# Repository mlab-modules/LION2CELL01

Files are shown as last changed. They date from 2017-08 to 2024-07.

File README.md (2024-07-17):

# LION2CELL01D - Li-ion dual-cell Battery Management Module

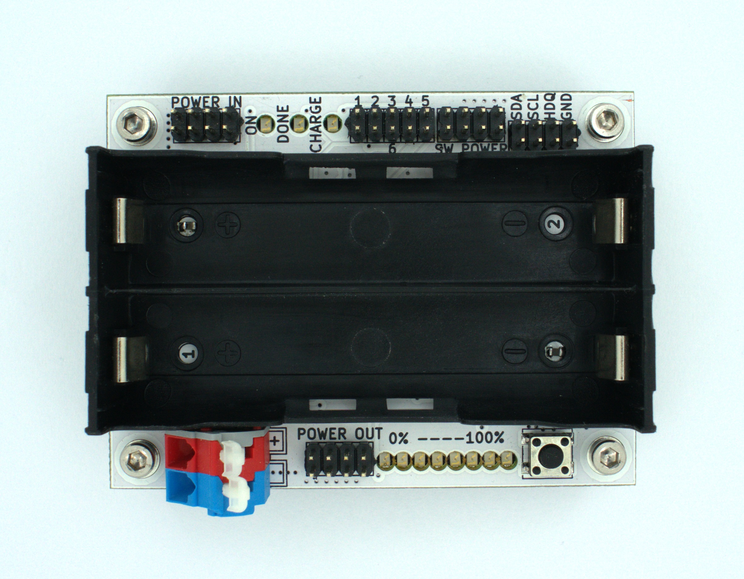
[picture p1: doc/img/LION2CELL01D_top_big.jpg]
LION2CELL01D


## Description

The LION2CELL01D is an integrated battery management solution for 18650 Li-ion batteries. It is designed to manage the charging, balancing, and monitoring of two series-connected Li-ion cells. This module measures the remaining energy, voltage, and temperature of the batteries, and protects against over-voltage and over-draining conditions.

## Features

- **Charging and Balancing**: Supports charging, balancing, and termination with temperature protection.
- **Gas-gauging**: Temperature-compensated gas-gauging for accurate remaining energy estimation.
- **Protection**: Over-voltage, over-current protection, but no under-voltage protection (the module operates until battery depletion).
- **Communication**: Supports I2C and HDQ communication interfaces.

## Technical Specifications

- **Power Supply**: 12 V @ 2 A
- **Charging Current**: Factory set to approximately 1.3 A
- **Battery Holder**: 2x 18650
- **Interfaces**: I2C, HDQ
- **Integrated Circuits**:
  - BQ24103 for charging
  - BQ34Z100 for fuel gauging
- **Dimensions**: 80.77 x 60.45 x 16 mm

## Connection

| Pin | Signal | Description |
|-----|---|---|
| 1 | PG | Power Good |
| 2 | STAT2  | Status Indicator  |
| 3 | GND | Ground |
| 4 | CE | Chip Enable |
| 5 | STAT1  | Status Indicator  |
| 6 | CMODE  | Configuration Mode|

## Construction

The module is constructed with three main functional blocks:
1. **Charging Circuitry**: Manages the charging process of the two series-connected Li-ion cells.
2. **Measurement Circuitry**: Measures the voltage, current, and temperature of the cells.
3. **Balancing and Protection Circuitry**: Ensures cell voltage balancing and provides protection against over-voltage.

### Important Considerations

- Regular charging is required (at least once every six months) to maintain the batteries within operational voltage ranges.
- Specific resistor values and settings are used for the voltage measurement, ensuring accurate readings without exceeding voltage limits.
- The module is equipped with a balancing circuit that discharges one of the cells to match the voltage of the other, with a discharge current around 10 mA.

## Setup and Configuration

1. **Installation**:
   - Check the PCB for proper soldering.
   - Insert the batteries in the designated order: position 1 first, followed by position 2.
   - Verify the operation of the charging function by connecting a 12V adapter.

2. **Software**:
   - Use `setguage2cell.py` to upload parameters to the energy measurement circuit.
   - Parameters are tailored for Panasonic NCR18650B or INR18650MJ1 cells; adjustments are needed for other types.
   - Conduct at least one charge/discharge cycle for accurate energy measurements.

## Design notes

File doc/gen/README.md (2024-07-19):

# PCB

Board size: 80.77x60.45 mm (3.18x2.38 inches)

- This is the size of the rectangle that contains the board
- Thickness: 1.6 mm (63 mils)
- Material: FR4
- Finish: HAL
- Layers: 2
- Copper thickness: 35 µm

Solder mask: TOP / BOTTOM

- Color: Green

Silk screen: TOP / BOTTOM

- Color: White

# Important sizes

Clearance: 0.2 mm (8 mils)

Track width: 0.18 mm (7 mils)

- By design rules: 0.2 mm (8 mils)

Drill: 0.6 mm (24 mils)

- Vias: 0.6 mm (24 mils) [Design: 0.4 mm (16 mils)]
- Pads: 0.7 mm (28 mils)
- The above values are real drill sizes, they add 0.1 mm (4 mils) to plated holes (PTH)

Via: 0.89/0.5 mm (35/20 mils)

- By design rules: 0.4/0.3 mm (16/12 mils)
- Micro via: yes [0.2/0.1 mm (8/4 mils)]
- Buried/blind via: yes
- Total: 267 (thru: 267 buried/blind: 0 micro: 0)

Outer Annular Ring: 0.15 mm (6 mils)

- By design rules: 0.26 mm (10 mils)

Eurocircuits class: 6A
- Using min drill 0.6 mm for an OAR of 0.15 mm

# General stats

Components count: (SMD/THT)

- Top: 2/20 (SMD + THT)
- Bottom: 70/8 (SMD + THT)

Defined tracks:

Used tracks:

- 0.18 mm (7 mils) (279) defined: no
- 0.2 mm (8 mils) (7) defined: no
- 0.25 mm (10 mils) (15) defined: no
- 0.25 mm (10 mils) (5) defined: no
- 0.3 mm (12 mils) (104) defined: no
- 0.4 mm (16 mils) (379) defined: no
- 0.5 mm (20 mils) (88) defined: no
- 0.6 mm (24 mils) (88) defined: no
- 0.89 mm (35 mils) (40) defined: no

Defined vias:

Used vias:

- 0.89/0.5 mm (35/20 mils) (Count: 267, Aspect: 1.8 A) defined: no

Holes (excluding vias):

- 0.6 mm (24 mils) (5)
- 0.89 mm (35 mils) (42)
- 1.0 mm (39 mils) (4)
- 1.3 mm (51 mils) (4)
- 1.6 mm (63 mils) (4)
- 2.7 mm (106 mils) (11)
- 3.0 mm (118 mils) (4)

Oval holes:

Drill tools (including vias and computing adjusts and rounding):

- 0.6 mm (24 mils) (267)
- 0.7 mm (28 mils) (5)
- 1.0 mm (39 mils) (42)
- 1.1 mm (43 mils) (4)
- 1.4 mm (55 mils) (4)
- 1.7 mm (67 mils) (4)
- 2.7 mm (106 mils) (11)
- 3.1 mm (122 mils) (4)

Solder paste stats:

Using a paste with 87.75 % alloy, that has an specific gravity for the alloy of 7.4 g/cm³
and 1.0 g/cm³ for the flux. This paste has an specific gravity of  4.15 g/cm³.

The stencil thickness is  0.12 mm.

| Side | Pads with paste | Area [mm²] | Paste [g] |
|---|---|---|---|
| Top | 4 | 4.97 | 0.02 |
| Bottom | 220 | 364.62 | 1.81 |
| Total  | 224 | 369.58 | 1.84 |

Note: this is just an approximation to the theoretical value. Margins of the solder mask and waste aren't computed.

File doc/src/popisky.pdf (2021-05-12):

List1

Stránka 1

1 – PG | 4 – CE | 1 – PG | 4 – CE | 1 – PG | 4 – CE
2 – STAT2 | 5 – STAT1 | 2 – STAT2 | 5 – STAT1 | 2 – STAT2 | 5 – STAT1
3 – GND | 6 – CMODE | 3 – GND | 6 – CMODE | 3 – GND | 6 – CMODE
1 – PG | 4 – CE | 1 – PG | 4 – CE | 1 – PG | 4 – CE
2 – STAT2 | 5 – STAT1 | 2 – STAT2 | 5 – STAT1 | 2 – STAT2 | 5 – STAT1
3 – GND | 6 – CMODE | 3 – GND | 6 – CMODE | 3 – GND | 6 – CMODE
1 – PG | 4 – CE | 1 – PG | 4 – CE | 1 – PG | 4 – CE
2 – STAT2 | 5 – STAT1 | 2 – STAT2 | 5 – STAT1 | 2 – STAT2 | 5 – STAT1
3 – GND | 6 – CMODE | 3 – GND | 6 – CMODE | 3 – GND | 6 – CMODE
1 – PG | 4 – CE | 1 – PG | 4 – CE | 1 – PG | 4 – CE
2 – STAT2 | 5 – STAT1 | 2 – STAT2 | 5 – STAT1 | 2 – STAT2 | 5 – STAT1
3 – GND | 6 – CMODE | 3 – GND | 6 – CMODE | 3 – GND | 6 – CMODE
1 – PG | 4 – CE | 1 – PG | 4 – CE | 1 – PG | 4 – CE
2 – STAT2 | 5 – STAT1 | 2 – STAT2 | 5 – STAT1 | 2 – STAT2 | 5 – STAT1
3 – GND | 6 – CMODE | 3 – GND | 6 – CMODE | 3 – GND | 6 – CMODE
1 – PG | 4 – CE | 1 – PG | 4 – CE | 1 – PG | 4 – CE
2 – STAT2 | 5 – STAT1 | 2 – STAT2 | 5 – STAT1 | 2 – STAT2 | 5 – STAT1
3 – GND | 6 – CMODE | 3 – GND | 6 – CMODE | 3 – GND | 6 – CMODE
1 – PG | 4 – CE | 1 – PG | 4 – CE | 1 – PG | 4 – CE
2 – STAT2 | 5 – STAT1 | 2 – STAT2 | 5 – STAT1 | 2 – STAT2 | 5 – STAT1
3 – GND | 6 – CMODE | 3 – GND | 6 – CMODE | 3 – GND | 6 – CMODE
1 – PG | 4 – CE | 1 – PG | 4 – CE | 1 – PG | 4 – CE
2 – STAT2 | 5 – STAT1 | 2 – STAT2 | 5 – STAT1 | 2 – STAT2 | 5 – STAT1
3 – GND | 6 – CMODE | 3 – GND | 6 – CMODE | 3 – GND | 6 – CMODE
1 – PG | 4 – CE | 1 – PG | 4 – CE | 1 – PG | 4 – CE
2 – STAT2 | 5 – STAT1 | 2 – STAT2 | 5 – STAT1 | 2 – STAT2 | 5 – STAT1
3 – GND | 6 – CMODE | 3 – GND | 6 – CMODE | 3 – GND | 6 – CMODE
1 – PG | 4 – CE | 1 – PG | 4 – CE | 1 – PG | 4 – CE
2 – STAT2 | 5 – STAT1 | 2 – STAT2 | 5 – STAT1 | 2 – STAT2 | 5 – STAT1
3 – GND | 6 – CMODE | 3 – GND | 6 – CMODE | 3 – GND | 6 – CMODE
1 – PG | 4 – CE | 1 – PG | 4 – CE | 1 – PG | 4 – CE
2 – STAT2 | 5 – STAT1 | 2 – STAT2 | 5 – STAT1 | 2 – STAT2 | 5 – STAT1
3 – GND | 6 – CMODE | 3 – GND | 6 – CMODE | 3 – GND | 6 – CMODE
1 – PG | 4 – CE | 1 – PG | 4 – CE | 1 – PG | 4 – CE
2 – STAT2 | 5 – STAT1 | 2 – STAT2 | 5 – STAT1 | 2 – STAT2 | 5 – STAT1
3 – GND | 6 – CMODE | 3 – GND | 6 – CMODE | 3 – GND | 6 – CMODE
1 – PG | 4 – CE | 1 – PG | 4 – CE | 1 – PG | 4 – CE
2 – STAT2 | 5 – STAT1 | 2 – STAT2 | 5 – STAT1 | 2 – STAT2 | 5 – STAT1
3 – GND | 6 – CMODE | 3 – GND | 6 – CMODE | 3 – GND | 6 – CMODE

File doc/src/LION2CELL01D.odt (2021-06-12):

Modul obsluhující dva sériově zapojené li-on články 18650

Jan Chroust

## Modul je osazen obvodem pro zajištění nabíjení dvou sériově zapojených li-on článků. Samozřejmostí je moderní obvod pro měření zbývající energie a celkové monitorování článků. Výstupem je I2C sběrnice. Článek je ošetřen proti případnému poškození přepětím.

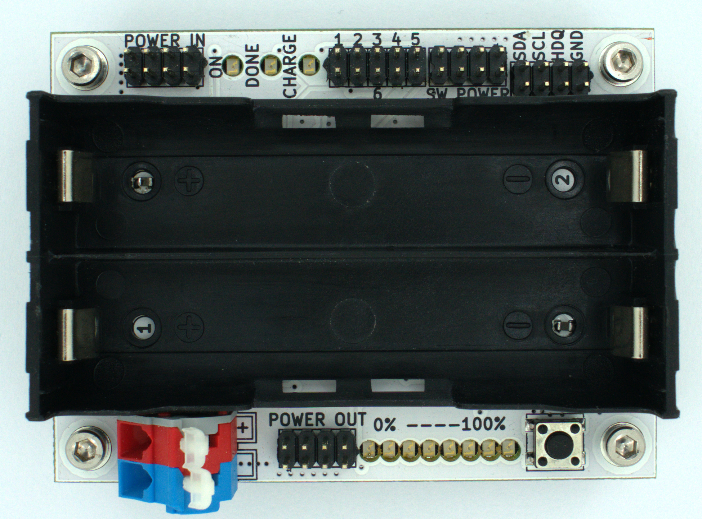
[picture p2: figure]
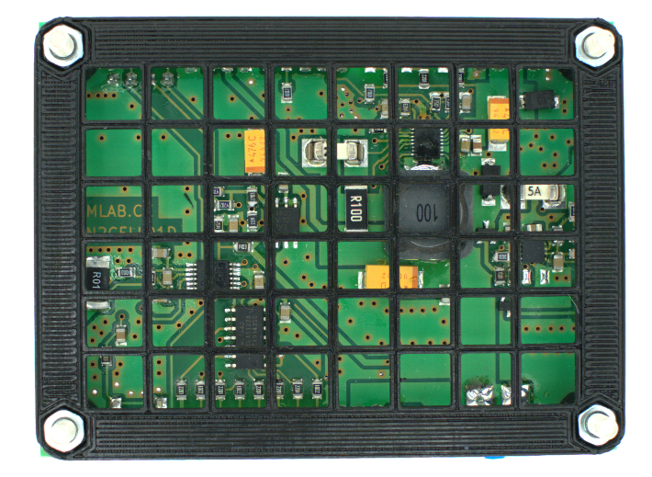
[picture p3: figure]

# Technické parametry

Parametr | Hodnota | Poznámka
Napájení | 12 V@2A | Nabíjecí proud je z výroby nastaven na cca 1,3A
Pouzdro na články | 2x18650
Rozhraní | I2C, HDQ
Integrované obvod: | BQ24103 | Nabíjení
| BQ34Z100 | Měření článku
Rozměry | 80.77 x 60.45 x 16 mm | Výška nad základní deskou

# Popis konstrukce

Modul obsahuje tři samostatné funkční celky – Dobíjecí elektroniku, měření parametrů a balanční a ochranný obvod. Většina z nich pracuje stále i když modul není využíván. Důsledkem je, že modul je nutné pravidelně nabíjet (alespoň jednou za půl roku), aby byly akumulátory udržovány v provozním rozsahu napětí.

## Nastavení děliče u BQ34Z100 pro měření napětí

Dělič pro měření napětí je tvořen odpory R23 a R24. Hodnota napětí na pinu BAT nesmí přesáhnout 900 mV, proto se hodnota odporu vypočítá následujícím vzorcem:

{R} rsub {24} =16500 Ω ( {V} rsub {in max} -900mV)/900mV

Výsledkem je pro dva články 137,5 kΩ, ale z důvodu lepší dostupnosti byl zvolen obvod R24 140kΩ. R23 16k5.

Výpočet hodnoty dělícího poměru v mV, který se zapisuje do nastavení obvodu se dopočítá tímto vzorcem:

Poměr= {1000} over {{R} rsub {23}} *( {R} rsub {23} + {R} rsub {24} )

Po vložení hodnot:

Poměr= {1000} over {16,5} *(16,5+140)

Výsledná hodnota poměru:

Poměr=9484 mV

Po převod na HEX (tato hodnota se vkládá):

Poměr=250C

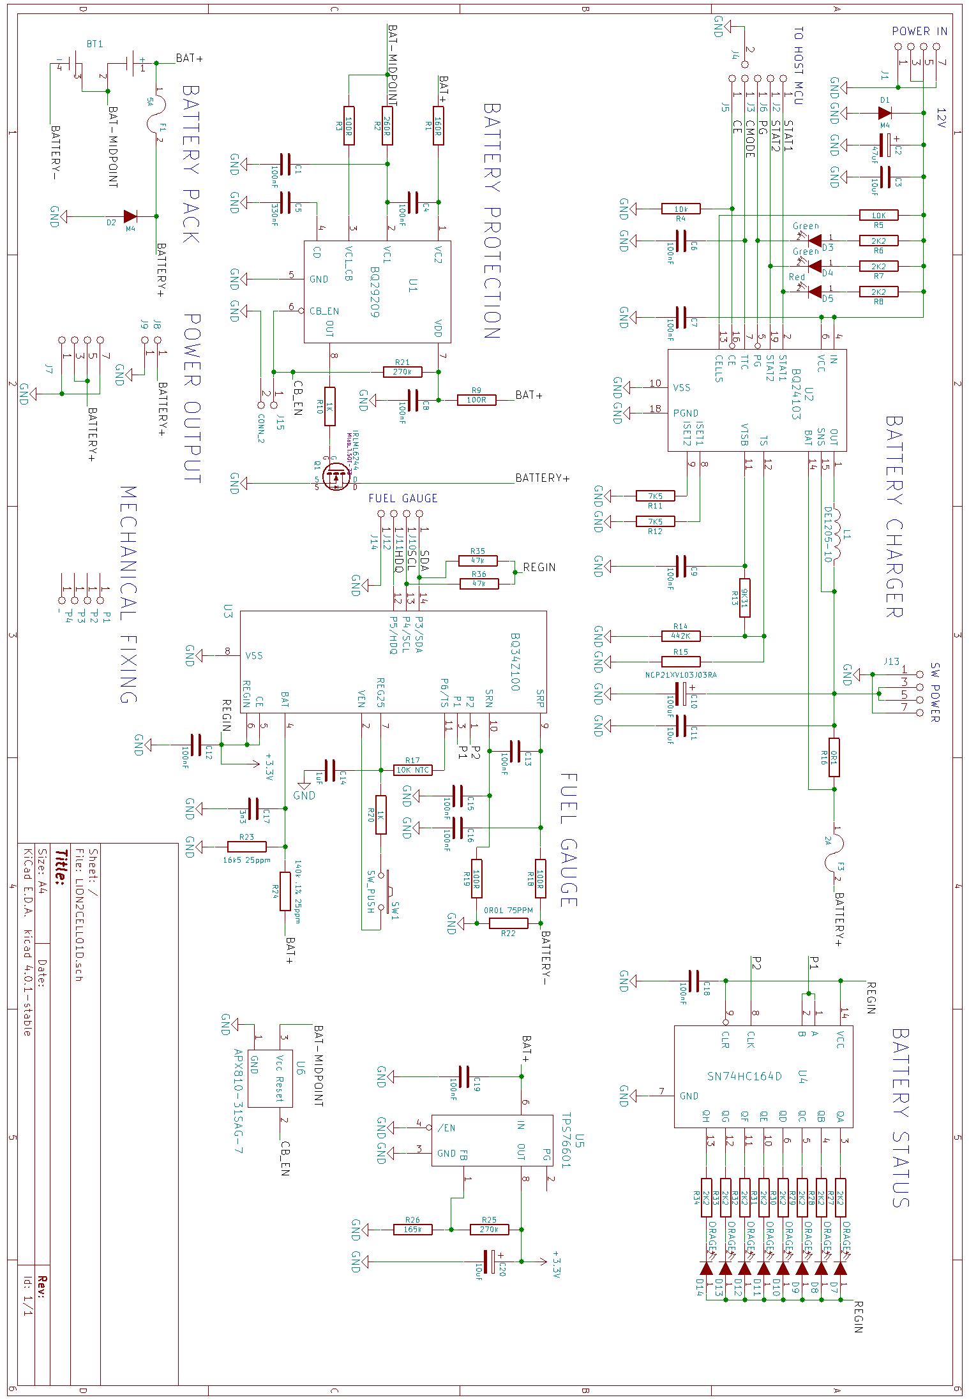
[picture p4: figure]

# Schéma

# Osazení a oživení

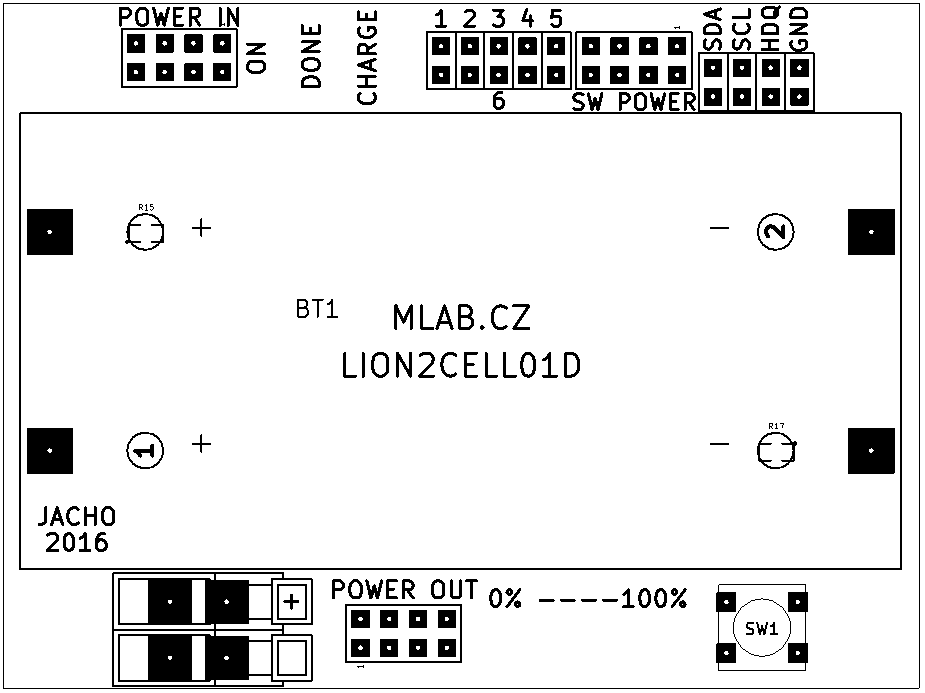
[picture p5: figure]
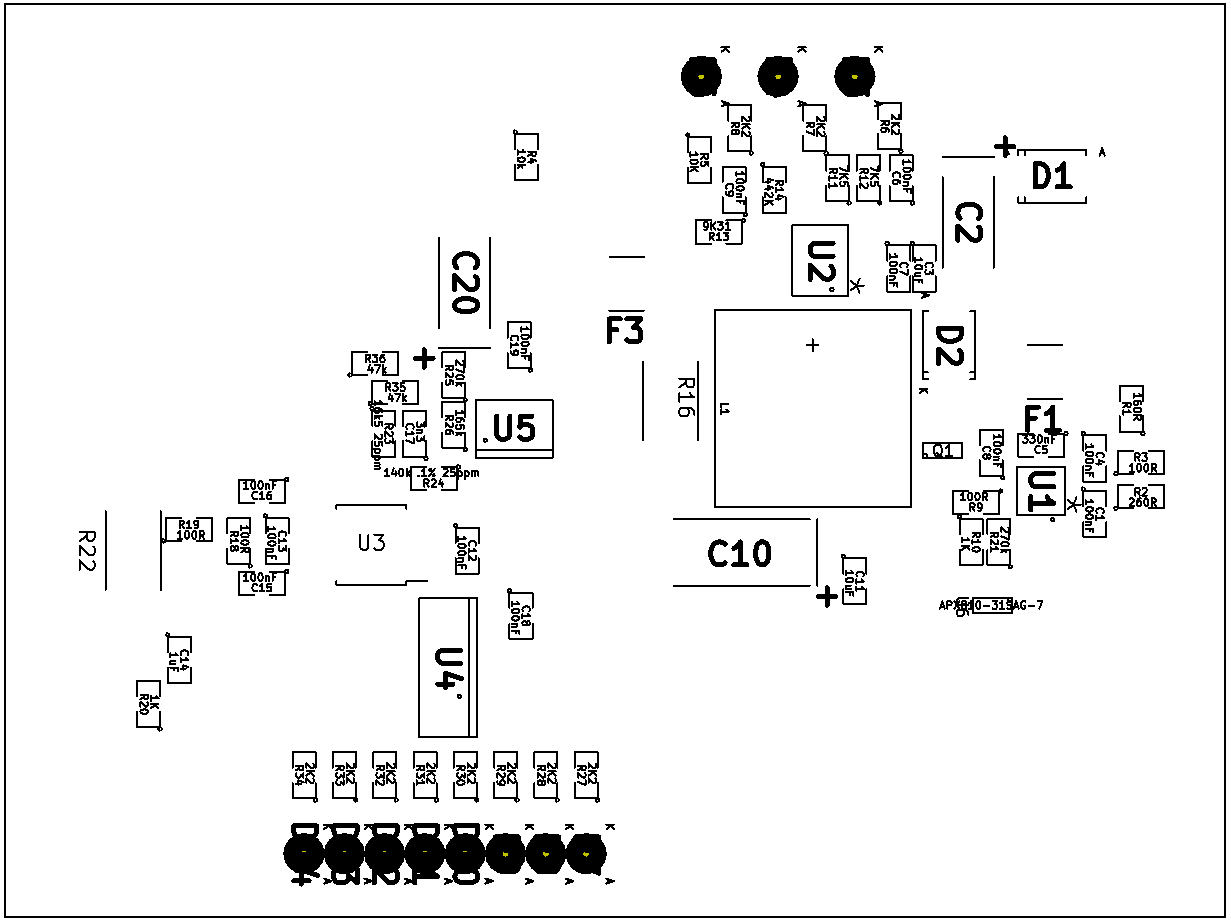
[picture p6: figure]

### Osazení

Označení | Typ | Pouzdro | Počet
BT1 | 2x18650_LION-RESCUE-LION2CELL01C | 2LION | 1
C1,C4,C6,C7,C8,C9,C12,C13,C15,C16,C18,C19 | 100nF | SMD-0805 | 12
C2 | 47uF | TantalC_SizeC_Reflow | 1
C3,C11 | 10uF | SMD-0805 | 2
C5 | 330nF | SMD-0805 | 1
C14 | 1uF | SMD-0805 | 1
C17 | 3n3 | SMD-0805 | 1
D1,D2 | M4 | SMA_Standard | 2
J1,J7,J13 | JUMP_4X2 | Straight_2x04 | 3
J2,J3,J5,J6,J10,J11,J12,J14 | JUMP_2x1 | Straight_1x02 | 8
J4 | JUMP2_2x1 | Straight_1x02 | 1
J8,J9 | CONN1_1 | WAGO256 | 2
L1 | DE1205-10 | DE1205-10 | 1
P1,P2,P3,P4 | _ | MountingHole_3mm | 4
Q1 | IRLML6244 | SOT-23 | 1
R1 | 160R | SMD-0805 | 1
R2 | 260R | SMD-0805 | 1
R3,R9,R18,R19 | 100R | SMD-0805 | 4
R4 | 10k | SMD-0805 | 1
R5 | 10K | SMD-0805 | 1
R6,R7,R8,R27,R28,R29,R30,R31,R32,R33,R34 | 2K2 | SMD-0805 | 11
R10,R20 | 1K | SMD-0805 | 2
R11,R12 | 7K5 | SMD-0805 | 2
R13 | 9K31 | SMD-0805 | 1
R14 | 442K | SMD-0805 | 1
R15 | NCP21XV103J03RA | SMD-0805 | 1
R16 | 0R1 | R_2512 | 1
R17 | 10K NTC | SMD-0805 | 1
R21,R25 | 270k | SMD-0805 | 2
R23 | 16k5 25ppm | SMD-0805 | 1
R24 | 140k .1% 25ppm | SMD-0805 | 1
R26 | 165k | SMD-0805 | 1
U4 | SN74HC164D | SO-14 | 1
SW1 | SW_PUSH | SW_PUSH_SMALL | 1
U3 | BQ34Z100 | TSSOP-14_4.4x5mm_Pitch0.65mm | 1
U1 | BQ29209 | VSON-8 | 1
C10 | 100uF | TantalC_SizeD_Reflow | 1
U2 | BQ24103 | VQFN-20 | 1
F1 | 5A | Drzak_2410 | 1
F3 | 2A | Drzak_2410 | 1
D7,D8,D9,D10,D11,D12,D13,D14 | ORAGE | LED_1206 | 8
D3,D4 | Green | LED_1206 | 2
D5 | Red | LED_1206 | 1
J15 | CONN_2 | SMD_1_2x2 | 1
C20 | 10uF | TantalC_SizeC_Reflow | 1
U5 | TPS76601 | SO-8 | 1
R35,R36 | 47k | SMD-0805 | 2
U6 | APX810-31SAG-7 | SOT-23 | 1
R22 | 0R01 75PPM | SMD-2512 | 1
Šrouby | M3x16 DIN 912 | | 4
3D tištěná podložka | | | 1

Při osazování svorkovnice J8/9, které jsou spojené do jednoho dílu je nutné uříznout přečnívající čudliky z červené části. Jinak se svorkovnice odklání od bateriového pouzdra.

3D tištěná podložka má po tisku zaslepené otvory technologickým mostem. Ten je potřeba po tisku odvrtat vrtákem o průměru 3mm. Odvrtávání je nelepší provést akušroubovákem nebo vrtačkou přepnutou na zpětný běh (tj. Opačně než by se normálně vrtákem vrtalo), tím je dosaženo přesnějšího otvoru v mostu.

### Oživení

Nejprve je dobré zkontrolovat PCB, zda je dobře zapájené. Následně se mohou vložit baterie. Je potřeba dodržet pořadí vyznačené pod pouzdrem. Nejprve se vkládá baterie do pozice 1 a pak teprve do pozice 2. Prohození pořadí může způsobit, že se modul nebude chovat správně. Po vložení posledního článku se rozsvítí oranžové LED pro diagnostiku zbývající energie článků.

Dále je vhodné vyzkoušet, zda je funkční funkce nabíjení.

Po zapojení 12V adaptéru by se měla rozsvítit zelená LED detekující připojení napájení. Následně by se měla rozsvítit červená LED indikující, že modul nabíjí. Po ukončení nabíjení druhá zelená LED indikující plně nabité akumulátory.

Program setguage2cell.py (https://github.com/mlab-modules/LION2CELL01/blob/LION2CELL01D/sw/setguage2cell.py) pro nahrání parametrů do obvodu pro měření energie článků se nachází ve složce sw (https://github.com/mlab-modules/LION2CELL01/tree/LION2CELL01D/sw) repozitáře modulu. Program používá knihovnu PyMLAB (https://github.com/MLAB-project/pymlab), kterou je potřeba mít nainstalovánu. Potom je možné modul nastavit příkazem

$ setguage2cell.py (https://github.com/mlab-modules/LION2CELL01/blob/LION2CELL01D/sw/setguage2cell.py) 8 NCR18650B

Nejsnadnější použití je pomocí modulu USBI2C01A (https://github.com/MLAB-project/Modules/tree/master/comm_serial/USBI2C01A).

Po nahrání parametrů pomocí setguage2cell.py (https://github.com/mlab-modules/LION2CELL01/blob/LION2CELL01D/sw/setguage2cell.py) je potřeba odpojit články a připojit je zpět v již popsaném pořadí. Toho lze nejsnadněji dosáhnout vražením nastříhaných plastových pásků mezi akumulátor a kontakty pouzdra. (Nastavení bez vložených akumulátorů nefunguje.)

Pro ověření, že je modul dobře zkonfigurován, slouží druhý program guage.py (https://github.com/mlab-modules/LION2CELL01/blob/LION2CELL01D/sw/guage.py), který vyčítá naměřená data.

Parametry, které se nahrávají do obvodu odpovídají článku 18650 od firmy Panasonic typ NCR18650B a nebo volitelně INR18650MJ1. V případě užití jiných akumulátorů, je potřeba nahrávané parametry změnit ve zdrojovém kódu setguage2cell.py (https://github.com/mlab-modules/LION2CELL01/blob/LION2CELL01D/sw/setguage2cell.py)! Jinak modul sice bude fungovat, ale udávaná data o kapacitě článků nebudou spolehlivá. Měření napětí na článcích, protékajícího proudu a teploty článku bude v pořádku.

Po vložení článků je potřeba provést minimálně jeden vybíjecí a nabíjecí cyklus, aby byly hodnoty zbývající energie přesnější. Čím déle budou články vloženy v modulu, tím budou měřené hodnoty přesnější. Pokud dojde k vyndání článků, tak měřící obvod resetuje měřené parametry a zpřesňování bude probíhat od začátku.

Modul je vybaven balančním obvodem, který vyrovnává napětí na obou článcích na stejnou hodnotu. Vyrovnávání se provádí tak, že jeden z článků je vybíjen. Tento vybíjecí proud měřící obvod zaznamenává. Pohybuje se řádově na hodnotě 10mA.

LION2CELL01D MLAB

LION2CELL01D / 2016-04-05 / jacho/ http://www.mlab.cz 7 / 7

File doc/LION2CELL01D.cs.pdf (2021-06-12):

## Modul obsluhující dva sériově zapojené li-on články

18650

Jan Chroust

Modul je osazen obvodem pro zajištění nabíjení dvou sériově zapojených li-on článků. Samozřejmostí je moderní obvod pro měření zbývající energie a celkové monitorování článků. Výstupem je I2C sběrnice. Článek je ošetřen proti případnému poškození přepětím.

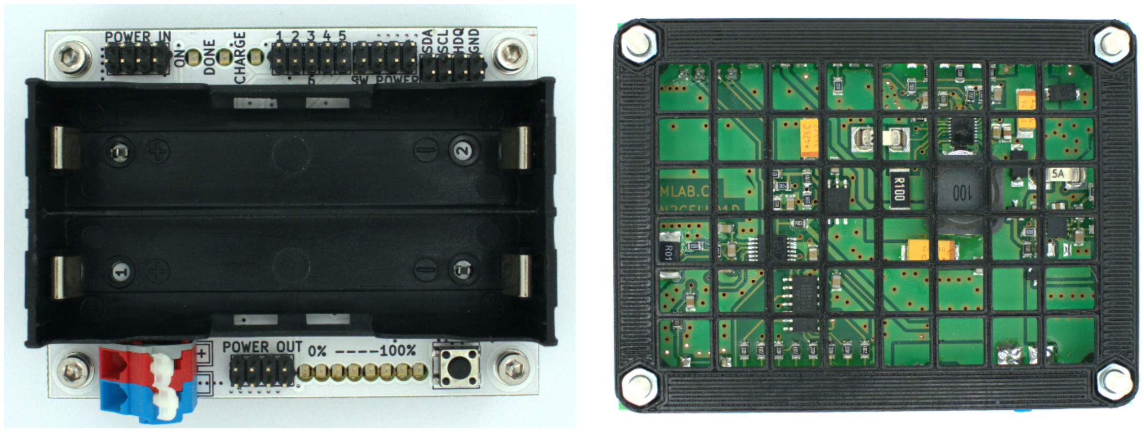
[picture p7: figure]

## 1 Technické parametry

Parametr | Hodnota | Poznámka
Napájení | 12 V@2A | Nabíjecí proud je z výroby nastaven na cca 1,3A
Pouzdro na články | 2x18650
Rozhraní | I2C, HDQ
Integrované obvod: | BQ24103 | Nabíjení
| BQ34Z100 | Měření článku
Rozměry | 80.77 x 60.45 x 16 mm | Výška nad základní deskou
LION2CELL01D / 2016-04-05 / jacho/ http://www.mlab.cz | 1 / 7
LION2CELL01D | MLAB

## 2 Popis konstrukce

Modul obsahuje tři samostatné funkční celky – Dobíjecí elektroniku, měření parametrů a balanční a ochranný obvod. Většina z nich pracuje stále i když modul není využíván. Důsledkem je, že modul je nutné pravidelně nabíjet (alespoň jednou za půl roku), aby byly akumulátory udržovány v provozním rozsahu napětí.

## Nastavení děliče u BQ34Z100 pro měření napětí

Dělič pro měření napětí je tvořen odpory R23 a R24. Hodnota napětí na pinu BAT nesmí přesáhnout 900 mV, proto se hodnota odporu vypočítá následujícím vzorcem: R24=16500Ω(V¿max−900mV )/900mV

Výsledkem je pro dva články 137,5 kΩ, ale z důvodu lepší dostupnosti byl zvolen obvod R24 140kΩ. R23 16k5.
Výpočet hodnoty dělícího poměru v mV, který se zapisuje do nastavení obvodu se dopočítá tímto vzorcem:

Poměr=

1000

R23

∗(R23+R24 )

Po vložení hodnot:

Poměr=

1000
16,5

∗(16,5+140)

Výsledná hodnota poměru:
Poměr=9484mV
Po převod na HEX (tato hodnota se vkládá): Poměr=250C
LION2CELL01D | MLAB

LION2CELL01D | MLAB

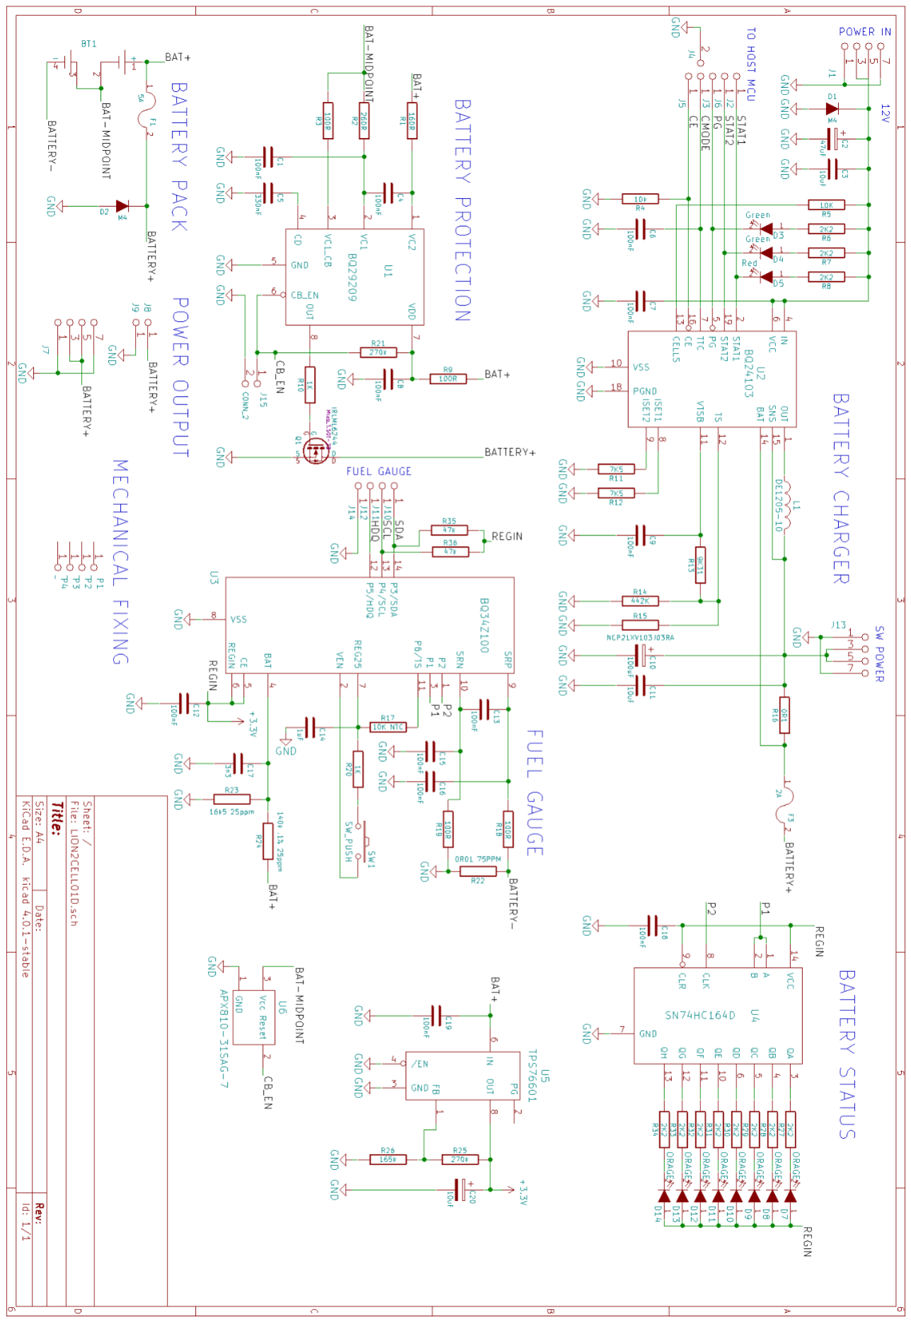
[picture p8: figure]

## Schéma

## 4 Osazení a oživení

LION2CELL01D | MLAB

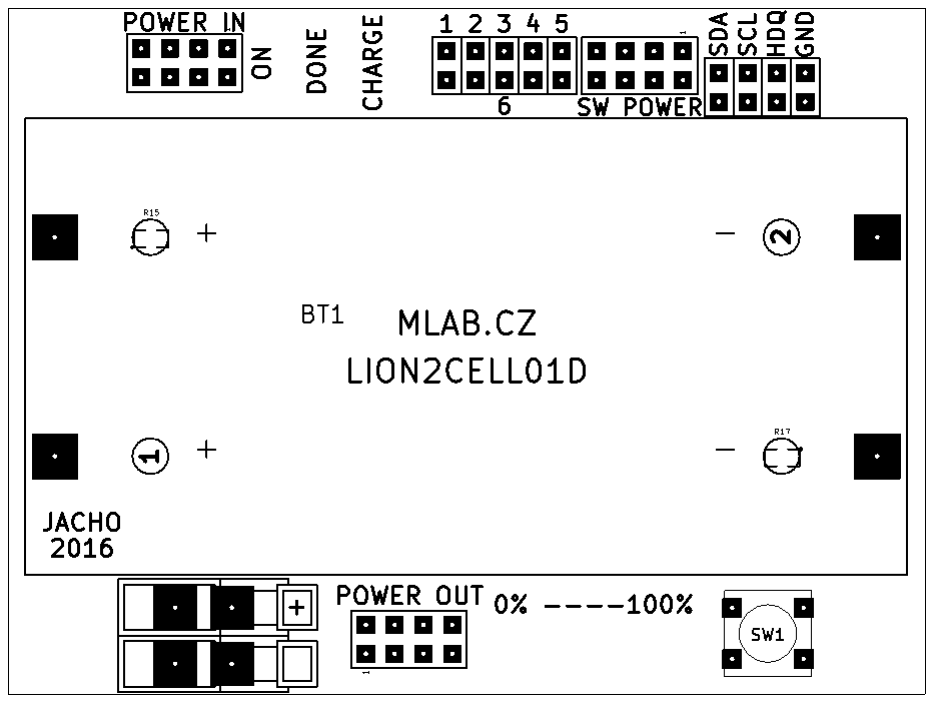
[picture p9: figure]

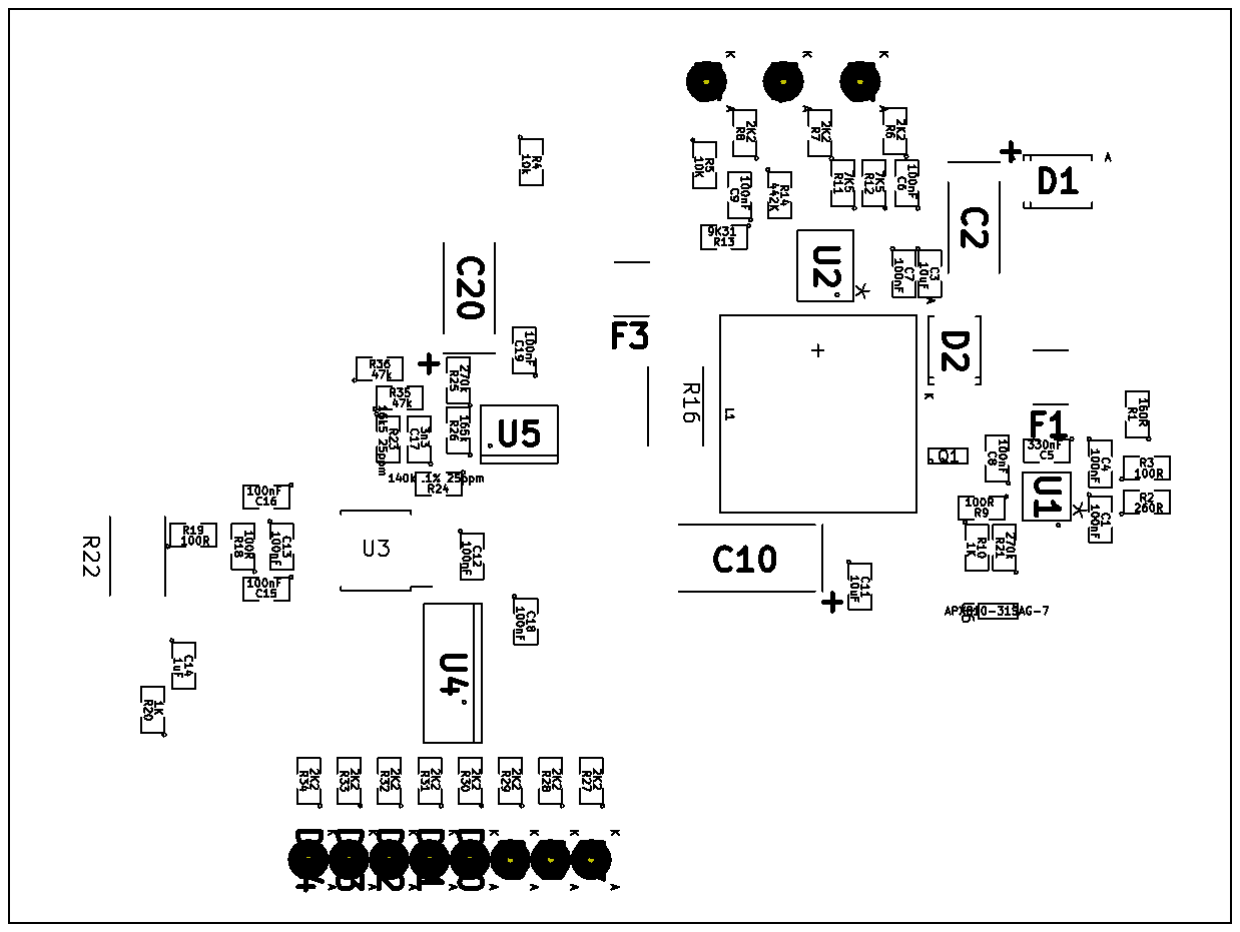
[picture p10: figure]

### 4.1.1 Osazení

Označení | Typ | Pouzdro | Počet
BT1 | 2x18650_LION-RESCUE-LION2CELL01C | 2LION | 1
C1,C4,C6,C7,C8,C9,C12,C13,C15,C16 ,C18,C19 | 100nF | SMD-0805 | 12
C2 | 47uF | TantalC_SizeC_Reflow | 1
C3,C11 | 10uF | SMD-0805 | 2
C5 | 330nF | SMD-0805 | 1
C14 | 1uF | SMD-0805 | 1
C17 | 3n3 | SMD-0805 | 1
D1,D2 | M4 | SMA_Standard | 2
J1,J7,J13 | JUMP_4X2 | Straight_2x04 | 3
J2,J3,J5,J6,J10,J11,J12,J14 | JUMP_2x1 | Straight_1x02 | 8
J4 | JUMP2_2x1 | Straight_1x02 | 1
J8,J9 | CONN1_1 | WAGO256 | 2
L1 | DE1205-10 | DE1205-10 | 1
P1,P2,P3,P4 | _ | MountingHole_3mm | 4
Q1 | IRLML6244 | SOT-23 | 1
LION2CELL01D | MLAB

R1 | 160R | SMD-0805 | 1
R2 | 260R | SMD-0805 | 1
R3,R9,R18,R19 | 100R | SMD-0805 | 4
R4 | 10k | SMD-0805 | 1
R5 | 10K | SMD-0805 | 1
R6,R7,R8,R27,R28,R29,R30,R31,R32, R33,R34 | 2K2 | SMD-0805 | 11
R10,R20 | 1K | SMD-0805 | 2
R11,R12 | 7K5 | SMD-0805 | 2
R13 | 9K31 | SMD-0805 | 1
R14 | 442K | SMD-0805 | 1
R15 | NCP21XV103J03RA | SMD-0805 | 1
R16 | 0R1 | R_2512 | 1
R17 | 10K NTC | SMD-0805 | 1
R21,R25 | 270k | SMD-0805 | 2
R23 | 16k5 25ppm | SMD-0805 | 1
R24 | 140k .1% 25ppm | SMD-0805 | 1
R26 | 165k | SMD-0805 | 1
U4 | SN74HC164D | SO-14 | 1
SW1 | SW_PUSH | SW_PUSH_SMALL | 1
U3 | BQ34Z100 | TSSOP-14_4.4x5mm_Pitch0.65m m | 1
U1 | BQ29209 | VSON-8 | 1
C10 | 100uF | TantalC_SizeD_Reflow | 1
U2 | BQ24103 | VQFN-20 | 1
F1 | 5A | Drzak_2410 | 1
F3 | 2A | Drzak_2410 | 1
D7,D8,D9,D10,D11,D12,D13,D14 | ORAGE | LED_1206 | 8
D3,D4 | Green | LED_1206 | 2
D5 | Red | LED_1206 | 1
J15 | CONN_2 | SMD_1_2x2 | 1
C20 | 10uF | TantalC_SizeC_Reflow | 1
U5 | TPS76601 | SO-8 | 1
R35,R36 | 47k | SMD-0805 | 2
U6 | APX810-31SAG-7 | SOT-23 | 1
R22 | 0R01 75PPM | SMD-2512 | 1
Šrouby | M3x16 DIN 912 | | 4
3D tištěná podložka | | | 1

Při osazování svorkovnice J8/9, které jsou spojené do jednoho dílu je nutné uříznout přečnívající čudliky z červené části. Jinak se svorkovnice odklání od bateriového pouzdra.

LION2CELL01D | MLAB

3D tištěná podložka má po tisku zaslepené otvory technologickým mostem. Ten je potřeba po tisku odvrtat vrtákem o průměru 3mm. Odvrtávání je nelepší provést akušroubovákem nebo vrtačkou přepnutou na zpětný běh (tj. Opačně než by se normálně vrtákem vrtalo), tím je dosaženo přesnějšího otvoru v mostu.

### 4.1.2 Oživení

Nejprve je dobré zkontrolovat PCB, zda je dobře zapájené. Následně se mohou vložit baterie. Je potřeba dodržet pořadí vyznačené pod pouzdrem. Nejprve se vkládá baterie do pozice 1 a pak teprve do pozice 2. Prohození pořadí může způsobit, že se modul nebude chovat správně. Po vložení posledního článku se rozsvítí oranžové LED pro diagnostiku zbývající energie článků. Dále je vhodné vyzkoušet, zda je funkční funkce nabíjení.
Po zapojení 12V adaptéru by se měla rozsvítit zelená LED detekující připojení napájení. Následně by se měla rozsvítit červená LED indikující, že modul nabíjí. Po ukončení nabíjení druhá zelená LED indikující plně nabité akumulátory.
Program setguage2cell.py (https://github.com/mlab-modules/LION2CELL01/blob/LION2CELL01D/sw/setguage2cell.py) pro nahrání parametrů do obvodu pro měření energie článků se nachází ve složce sw (https://github.com/mlab-modules/LION2CELL01/tree/LION2CELL01D/sw) repozitáře modulu. Program používá knihovnu PyMLAB, (https://github.com/MLAB-project/pymlab) kterou je potřeba mít nainstalovánu. Potom je možné modul nastavit příkazem

$ setguage2cell.py (https://github.com/mlab-modules/LION2CELL01/blob/LION2CELL01D/sw/setguage2cell.py) 8 NCR18650B

Nejsnadnější použití je pomocí modulu USBI2C01A. (https://github.com/MLAB-project/Modules/tree/master/comm_serial/USBI2C01A)
Po nahrání parametrů pomocí setguage2cell.py (https://github.com/mlab-modules/LION2CELL01/blob/LION2CELL01D/sw/setguage2cell.py) je potřeba odpojit články a připojit je zpět v již popsaném pořadí. Toho lze nejsnadněji dosáhnout vražením nastříhaných plastových pásků mezi akumulátor a kontakty pouzdra. (Nastavení bez vložených akumulátorů nefunguje.)
Pro ověření, že je modul dobře zkonfigurován, slouží druhý program guage.py, (https://github.com/mlab-modules/LION2CELL01/blob/LION2CELL01D/sw/guage.py) který vyčítá naměřená data.
Parametry, které se nahrávají do obvodu odpovídají článku 18650 od firmy Panasonic typ NCR18650B a nebo volitelně INR18650MJ1. V případě užití jiných akumulátorů, je potřeba nahrávané parametry změnit ve zdrojovém kódu setguage2cell.py! (https://github.com/mlab-modules/LION2CELL01/blob/LION2CELL01D/sw/setguage2cell.py) Jinak modul sice bude fungovat, ale udávaná data o kapacitě článků nebudou spolehlivá. Měření napětí na článcích, protékajícího proudu a teploty článku bude v pořádku.
Po vložení článků je potřeba provést minimálně jeden vybíjecí a nabíjecí cyklus, aby byly hodnoty zbývající energie přesnější. Čím déle budou články vloženy v modulu, tím budou měřené hodnoty přesnější. Pokud dojde k vyndání článků, tak měřící obvod resetuje měřené parametry a zpřesňování bude probíhat od začátku.
Modul je vybaven balančním obvodem, který vyrovnává napětí na obou článcích na stejnou hodnotu. Vyrovnávání se provádí tak, že jeden z článků je vybíjen. Tento vybíjecí proud měřící obvod zaznamenává. Pohybuje se řádově na hodnotě 10mA.
LION2CELL01D | MLAB

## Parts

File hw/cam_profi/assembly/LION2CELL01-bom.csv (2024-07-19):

Component | Description | Part | References | Value | Footprint | Quantity Per PCB | Datasheet
1 |  | 2x18650_LION-RESCUE-LION2CELL01C | BT1 | 2x18650_LION-RESCUE-LION2CELL01C | 2LION | 1
2 |  | C-RESCUE-LION2CELL01C | C17 | 3n3 | SMD-0805 | 1
3 |  | C-RESCUE-LION2CELL01C | C1C4C6C7C8C9C12C13C15C16C18C19 | 100nF | SMD-0805 | 12
4 |  | C-RESCUE-LION2CELL01C | C5 | 330nF | SMD-0805 | 1
5 |  | C-RESCUE-LION2CELL01C | C14 | 1uF | SMD-0805 | 1
6 |  | C-RESCUE-LION2CELL01C | C3C11 | 10uF | SMD-0805 | 2
7 |  | CP2 | C20 | 10uF | TantalC_SizeB_Reflow | 1
8 |  | CP2 | C2 | 47uF | TantalC_SizeC_Reflow | 1
9 |  | CP2 | C10 | 100uF | TantalC_SizeD_Reflow | 1
10 |  | LED-RESCUE-LION2CELL01C | D3D4 | Green | LED_1206 | 2
11 |  | DIODE | D1D2 | M4 | SMA_Standard | 2
12 |  | LED-RESCUE-LION2CELL01C | D7D8D9D10D11D12D13D14 | ORAGE | LED_1206 | 8
13 |  | LED-RESCUE-LION2CELL01C | D5 | Red | LED_1206 | 1
14 |  | FUSE | F3 | 2A | Drzak_2410 | 1
15 |  | FUSE | F1 | 5A | Drzak_2410 | 1
16 |  | CONN1_1 | J8J9 | CONN1_1 | WAGO256 | 2
17 |  | CONN_2 | J15 | CONN_2 | SMD_1_2x2 | 1
18 |  | JUMP2_2x1 | J4 | JUMP2_2x1 |  | 1
19 |  | JUMP_2x1 | J2J3J5J6J10J11J12J14 | JUMP_2x1 | Straight_1x02 | 8
20 |  | JUMP_4X2 | J1J7J13 | JUMP_4X2 | Straight_2x04 | 3
21 |  | INDUCTOR_SMALL | L1 | DE1205-10 | DE1205-10 | 1
22 |  | MOSFET-N | Q1 | IRLML6244 | SOT-23 | 1
23 |  | R-RESCUE-LION2CELL01C | R16 | 0R1 | R_2512 | 1
24 |  | R-RESCUE-LION2CELL01C | R3R9R18R19 | 100R | SMD-0805 | 4
25 |  | R-RESCUE-LION2CELL01C | R1 | 160R | SMD-0805 | 1
26 |  | R-RESCUE-LION2CELL01C | R2 | 260R | SMD-0805 | 1
27 |  | R-RESCUE-LION2CELL01C | R10R20 | 1K | SMD-0805 | 2
28 |  | R-RESCUE-LION2CELL01C | R6R7R8R27R28R29R30R31R32R33R34 | 2K2 | SMD-0805 | 11
29 |  | R-RESCUE-LION2CELL01C | R11R12 | 7K5 | SMD-0805 | 2
30 |  | R-RESCUE-LION2CELL01C | R13 | 9K31 | SMD-0805 | 1
31 |  | R-RESCUE-LION2CELL01C | R4R5 | 10k | SMD-0805 | 2
32 |  | R-RESCUE-LION2CELL01C | R35R36 | 47k | SMD-0805 | 2
33 |  | R-RESCUE-LION2CELL01C | R26 | 165k | SMD-0805 | 1
34 |  | R-RESCUE-LION2CELL01C | R21R25 | 270k | SMD-0805 | 2
35 |  | R-RESCUE-LION2CELL01C | R14 | 442K | SMD-0805 | 1
36 |  | R-RESCUE-LION2CELL01C | R22 | 0R01 75PPM | SMD-2512 | 1
37 |  | R-RESCUE-LION2CELL01C | R17 | 10K NTC | SMD-0805 | 1
38 |  | R-RESCUE-LION2CELL01C | R24 | 140k .1% 25ppm | SMD-0805 | 1
39 |  | R-RESCUE-LION2CELL01C | R23 | 16k5 25ppm | SMD-0805 | 1
40 |  | R-RESCUE-LION2CELL01C | R15 | NCP21XV103J03RA | SMD-0805 | 1
41 |  | SW_PUSH | SW1 | SW_PUSH | SW_PUSH_SMALL | 1
42 |  | APX810-31SAG-7 | U6 | APX810-31SAG-7 | SOT-23 | 1
43 |  | BQ24103 | U2 | BQ24103 | VQFN-20 | 1
44 |  | BQ29209 | U1 | BQ29209 | VSON-8 | 1 | https://www.ti.com/lit/ds/symlink/bq29209.pdf
45 |  | BQ34Z100 | U3 | BQ34Z100 | TSSOP-14_4.4x5mm_Pitch0.65mm | 1
46 |  | SN74HC164D | U4 | SN74HC164D | SO-14 | 1
47 |  | TPS76601 | U5 | TPS76601 | SO-8 | 1

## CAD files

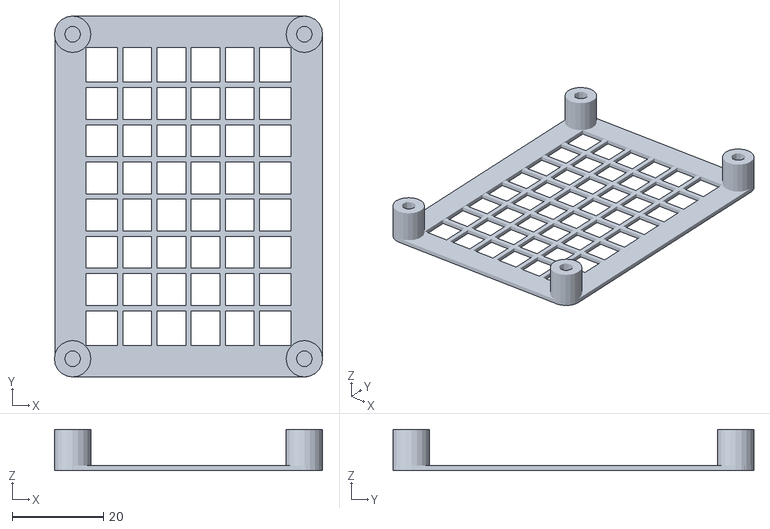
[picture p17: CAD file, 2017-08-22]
cad/6x8MLAB_frame.stl
58.8 x 79.1 x 9.00

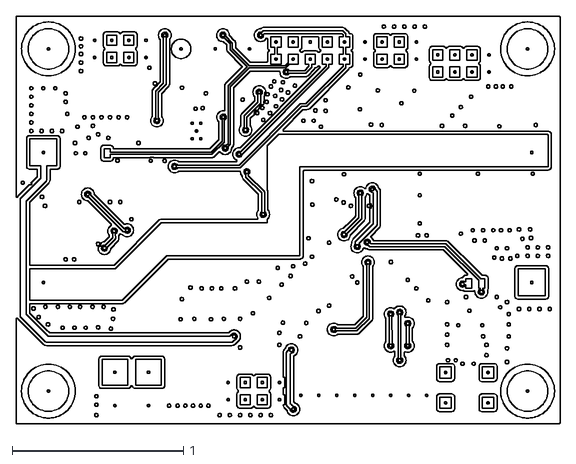
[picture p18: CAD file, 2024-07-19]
doc/gen/dxf/LION2CELL01-F_Cu.dxf
3.18 x 2.38

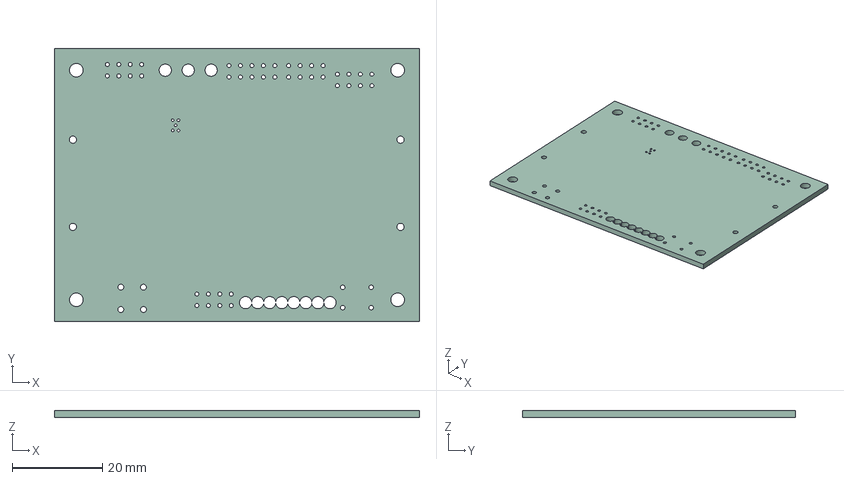
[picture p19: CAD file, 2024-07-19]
doc/gen/LION2CELL01.step
80.8 x 60.5 x 1.60 mm

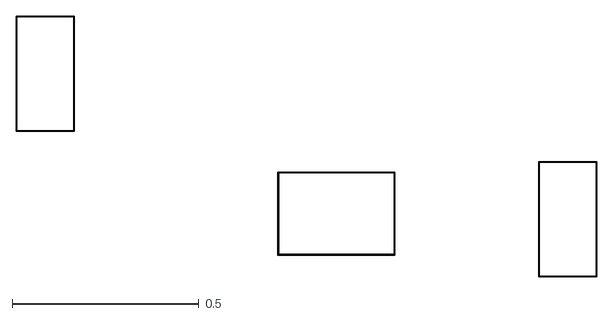
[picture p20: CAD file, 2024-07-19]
doc/gen/dxf/LION2CELL01-B_Courtyard.dxf
1.56 x 0.699

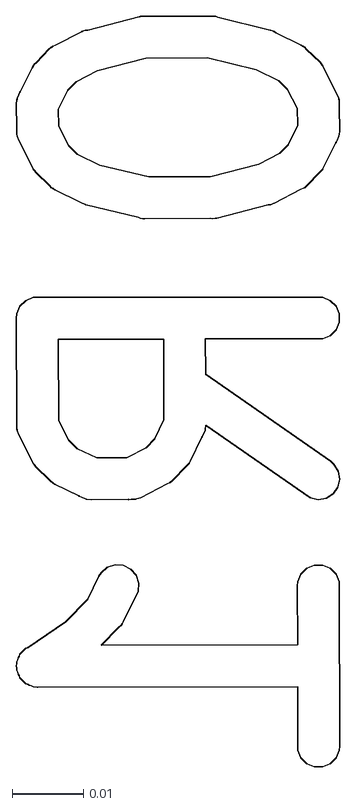
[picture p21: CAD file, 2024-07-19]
doc/gen/dxf/LION2CELL01-B_Fab.dxf
0.0453 x 0.105

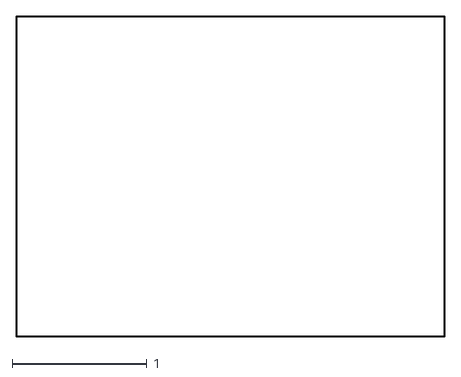
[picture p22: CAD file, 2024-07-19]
doc/gen/dxf/LION2CELL01-Edge_Cuts.dxf
3.18 x 2.38

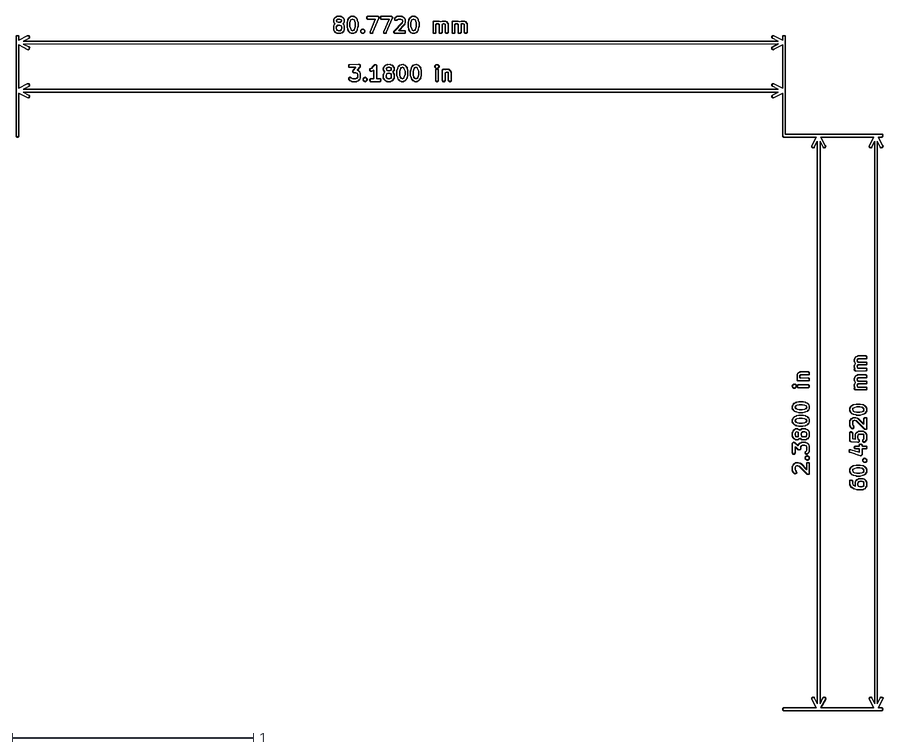
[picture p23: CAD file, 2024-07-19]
doc/gen/dxf/LION2CELL01-User_Drawings.dxf
3.60 x 2.88

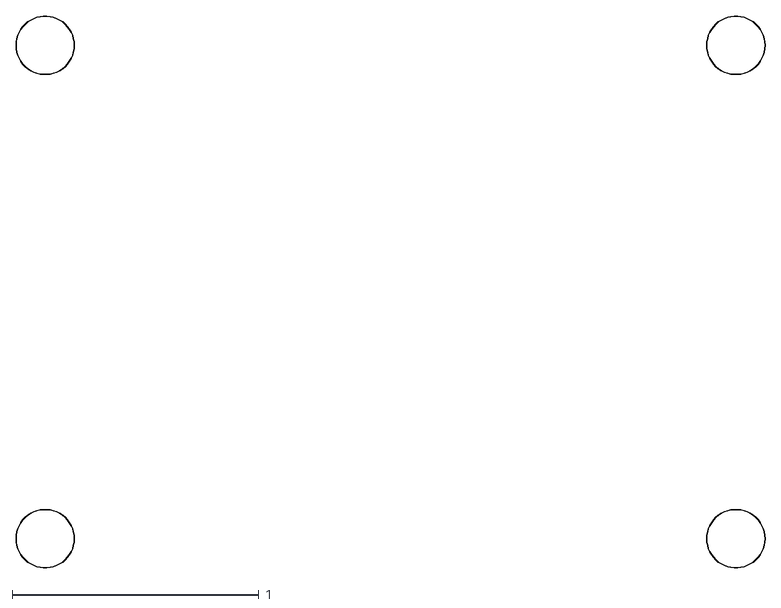
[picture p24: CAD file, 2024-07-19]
doc/gen/dxf/LION2CELL01-F_Adhesive.dxf
3.04 x 2.24

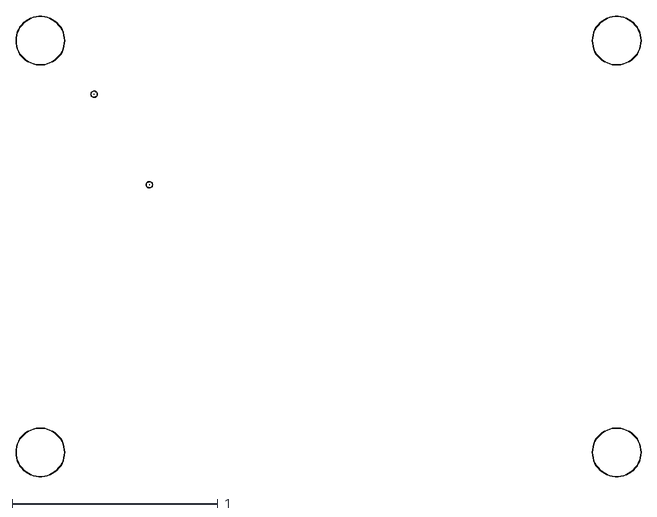
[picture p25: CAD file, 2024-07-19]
doc/gen/dxf/LION2CELL01-B_Adhesive.dxf
3.04 x 2.24

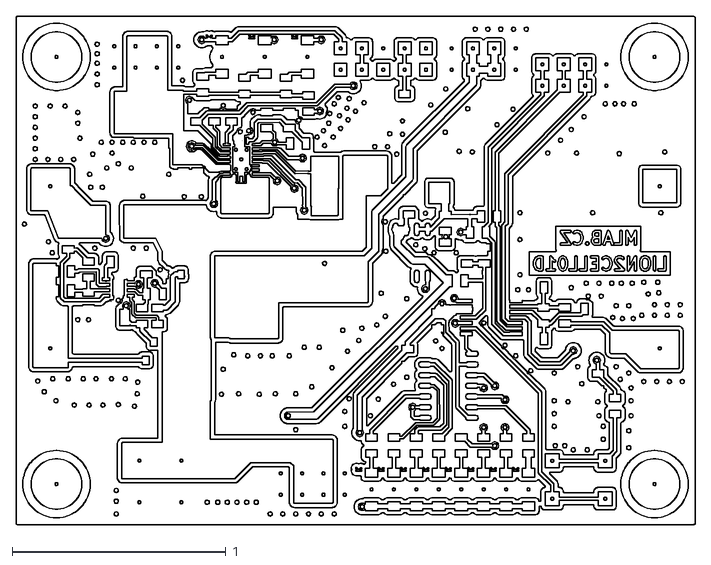
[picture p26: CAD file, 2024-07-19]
doc/gen/dxf/LION2CELL01-B_Cu.dxf
3.18 x 2.38

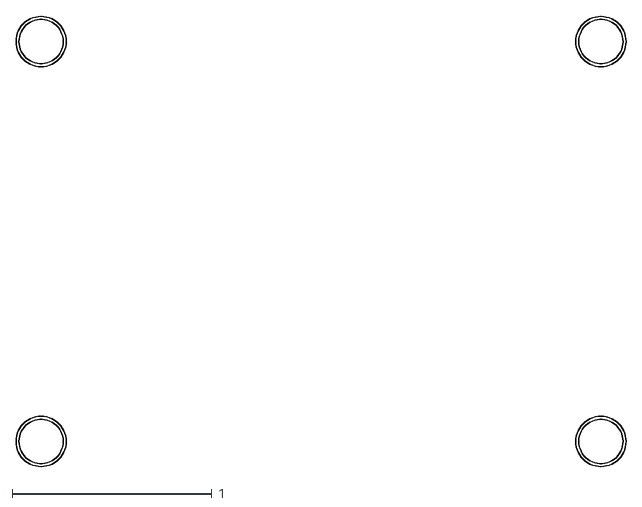
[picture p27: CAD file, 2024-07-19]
doc/gen/dxf/LION2CELL01-User_Comments.dxf
3.05 x 2.25

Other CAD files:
doc/gen/dxf/LION2CELL01-User_Eco1.dxf
doc/gen/dxf/LION2CELL01-User_Eco2.dxf
doc/gen/dxf/LION2CELL01-F_Courtyard.dxf
doc/gen/dxf/LION2CELL01-F_Fab.dxf
doc/gen/dxf/LION2CELL01-Margin.dxf
cad/src/6x8MLAB_frame.scad
doc/gen/dxf/LION2CELL01-B_Mask.dxf
doc/gen/dxf/LION2CELL01-B_Paste.dxf
doc/gen/dxf/LION2CELL01-B_Silkscreen.dxf
doc/gen/dxf/LION2CELL01-F_Mask.dxf
doc/gen/dxf/LION2CELL01-F_Paste.dxf
doc/gen/dxf/LION2CELL01-F_Silkscreen.dxf

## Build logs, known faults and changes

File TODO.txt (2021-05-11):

-zkusit udìlat díry na fasety
zkontrolovat přebíjení (změřením napětí na článcích při nabití a zapnutem menici) Toto je stav pri nabijeni a zaroven zapnutem pripojenem zarizeni (napr. odroid.).
-Vstup cells se muze zrusit. U dvouclankoveho modulu je minimalni pravdepodobnost, ze bude nekdy vyuzity. Vzniklo by tim vice mista pro napajeci vystup ktery je vedle. 
Nebo by misto tohoto pinu bylo vyhodnejsi vyvest stat2, ktery poskytuje informaci o stavu nabijeni.
-Hebinek CMODE/TTC by se hodil deleny, aby signal bylo mozne snadno uzemnit a tim modul prepnout do rezimu UPS.
 -zvetšit pouzdro meřiciho odporu proudu pokud to půjde
 -upravit popisky na 1234 u hrebinku pro jistotu

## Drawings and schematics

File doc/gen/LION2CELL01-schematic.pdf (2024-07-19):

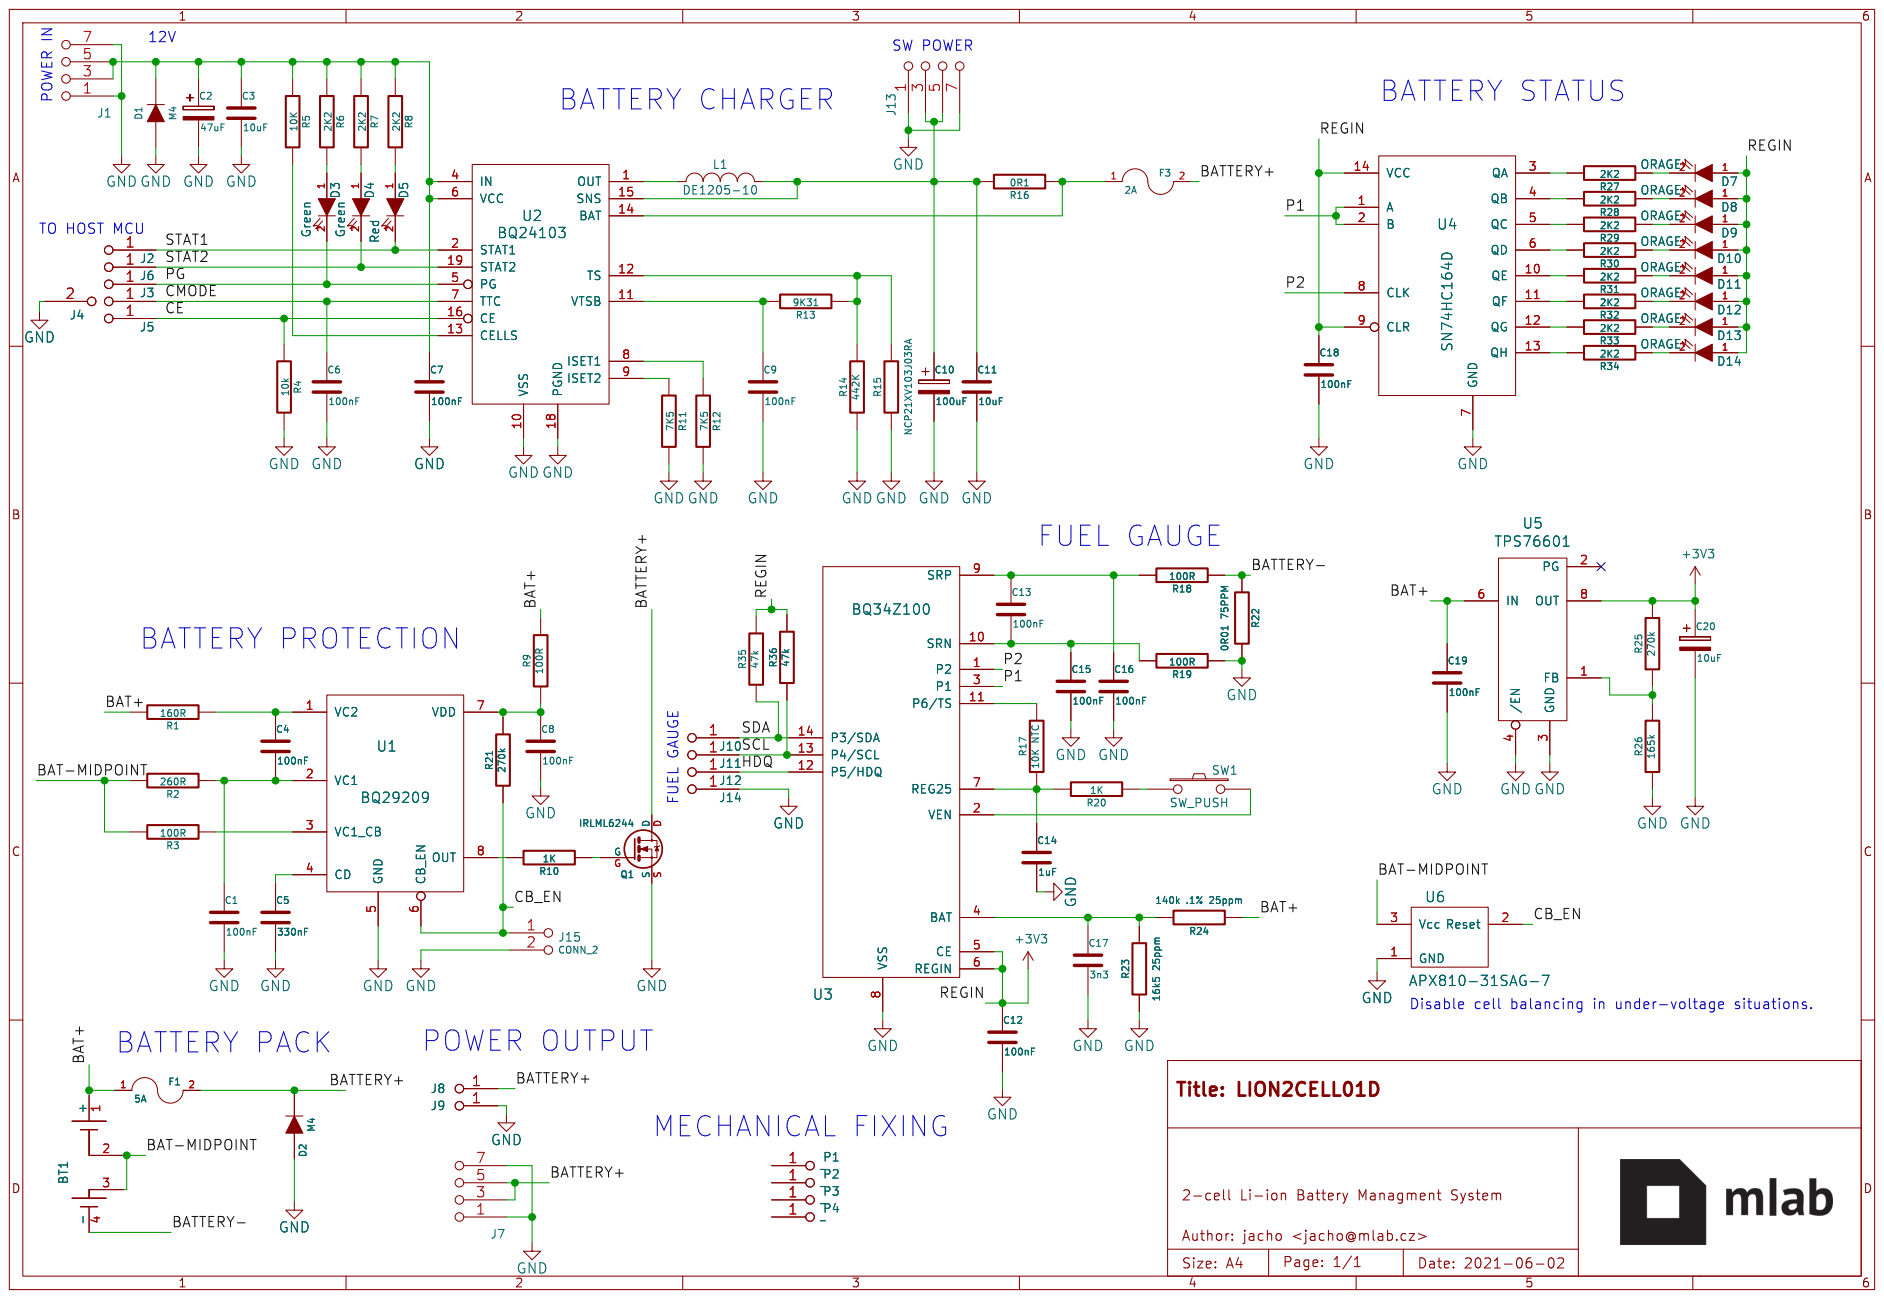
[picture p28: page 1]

7 CLK 8 CLR 9 U6 APX810-31SAG-7 GND 1 Reset 2 Vcc 3 GND

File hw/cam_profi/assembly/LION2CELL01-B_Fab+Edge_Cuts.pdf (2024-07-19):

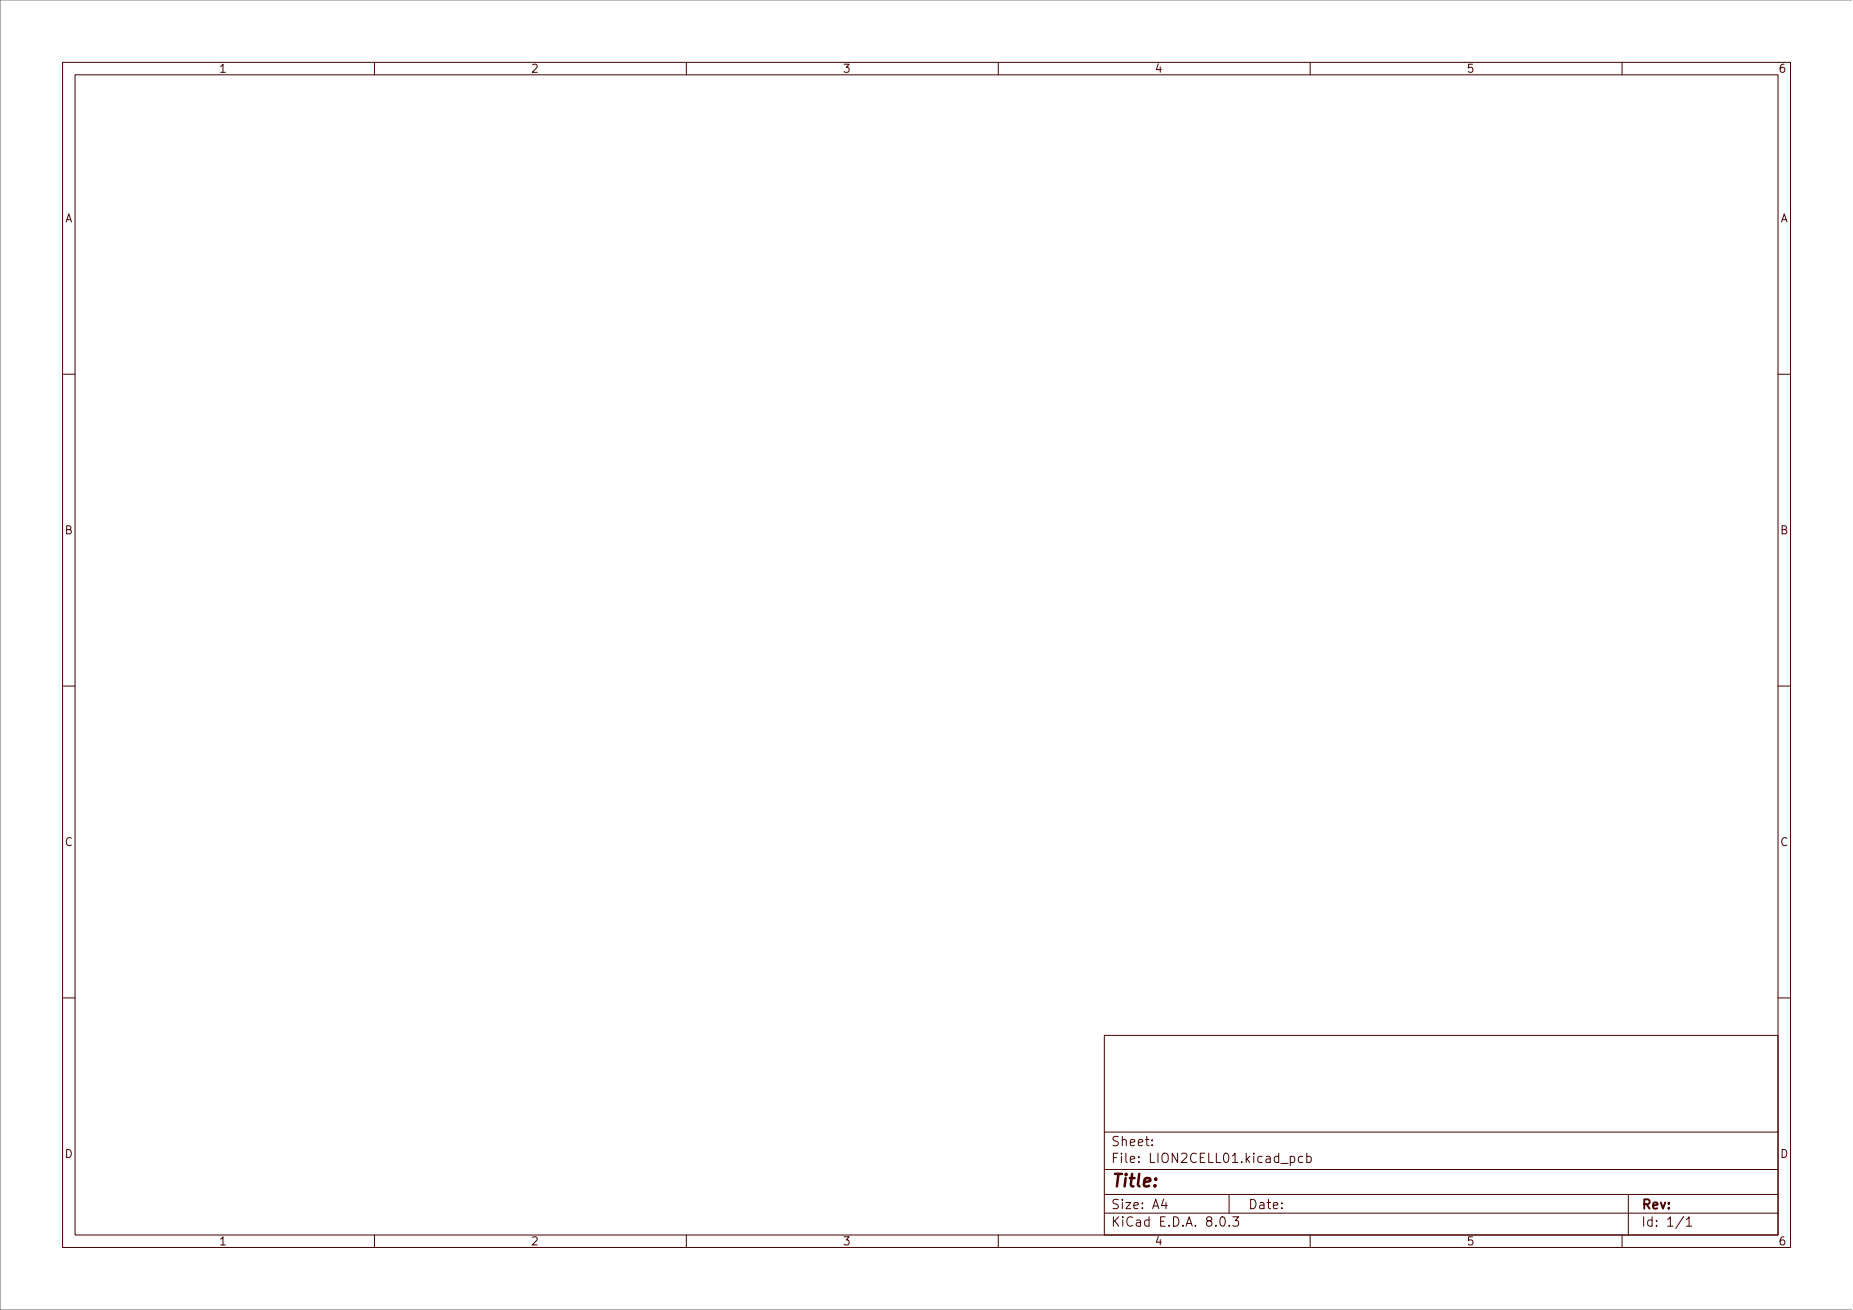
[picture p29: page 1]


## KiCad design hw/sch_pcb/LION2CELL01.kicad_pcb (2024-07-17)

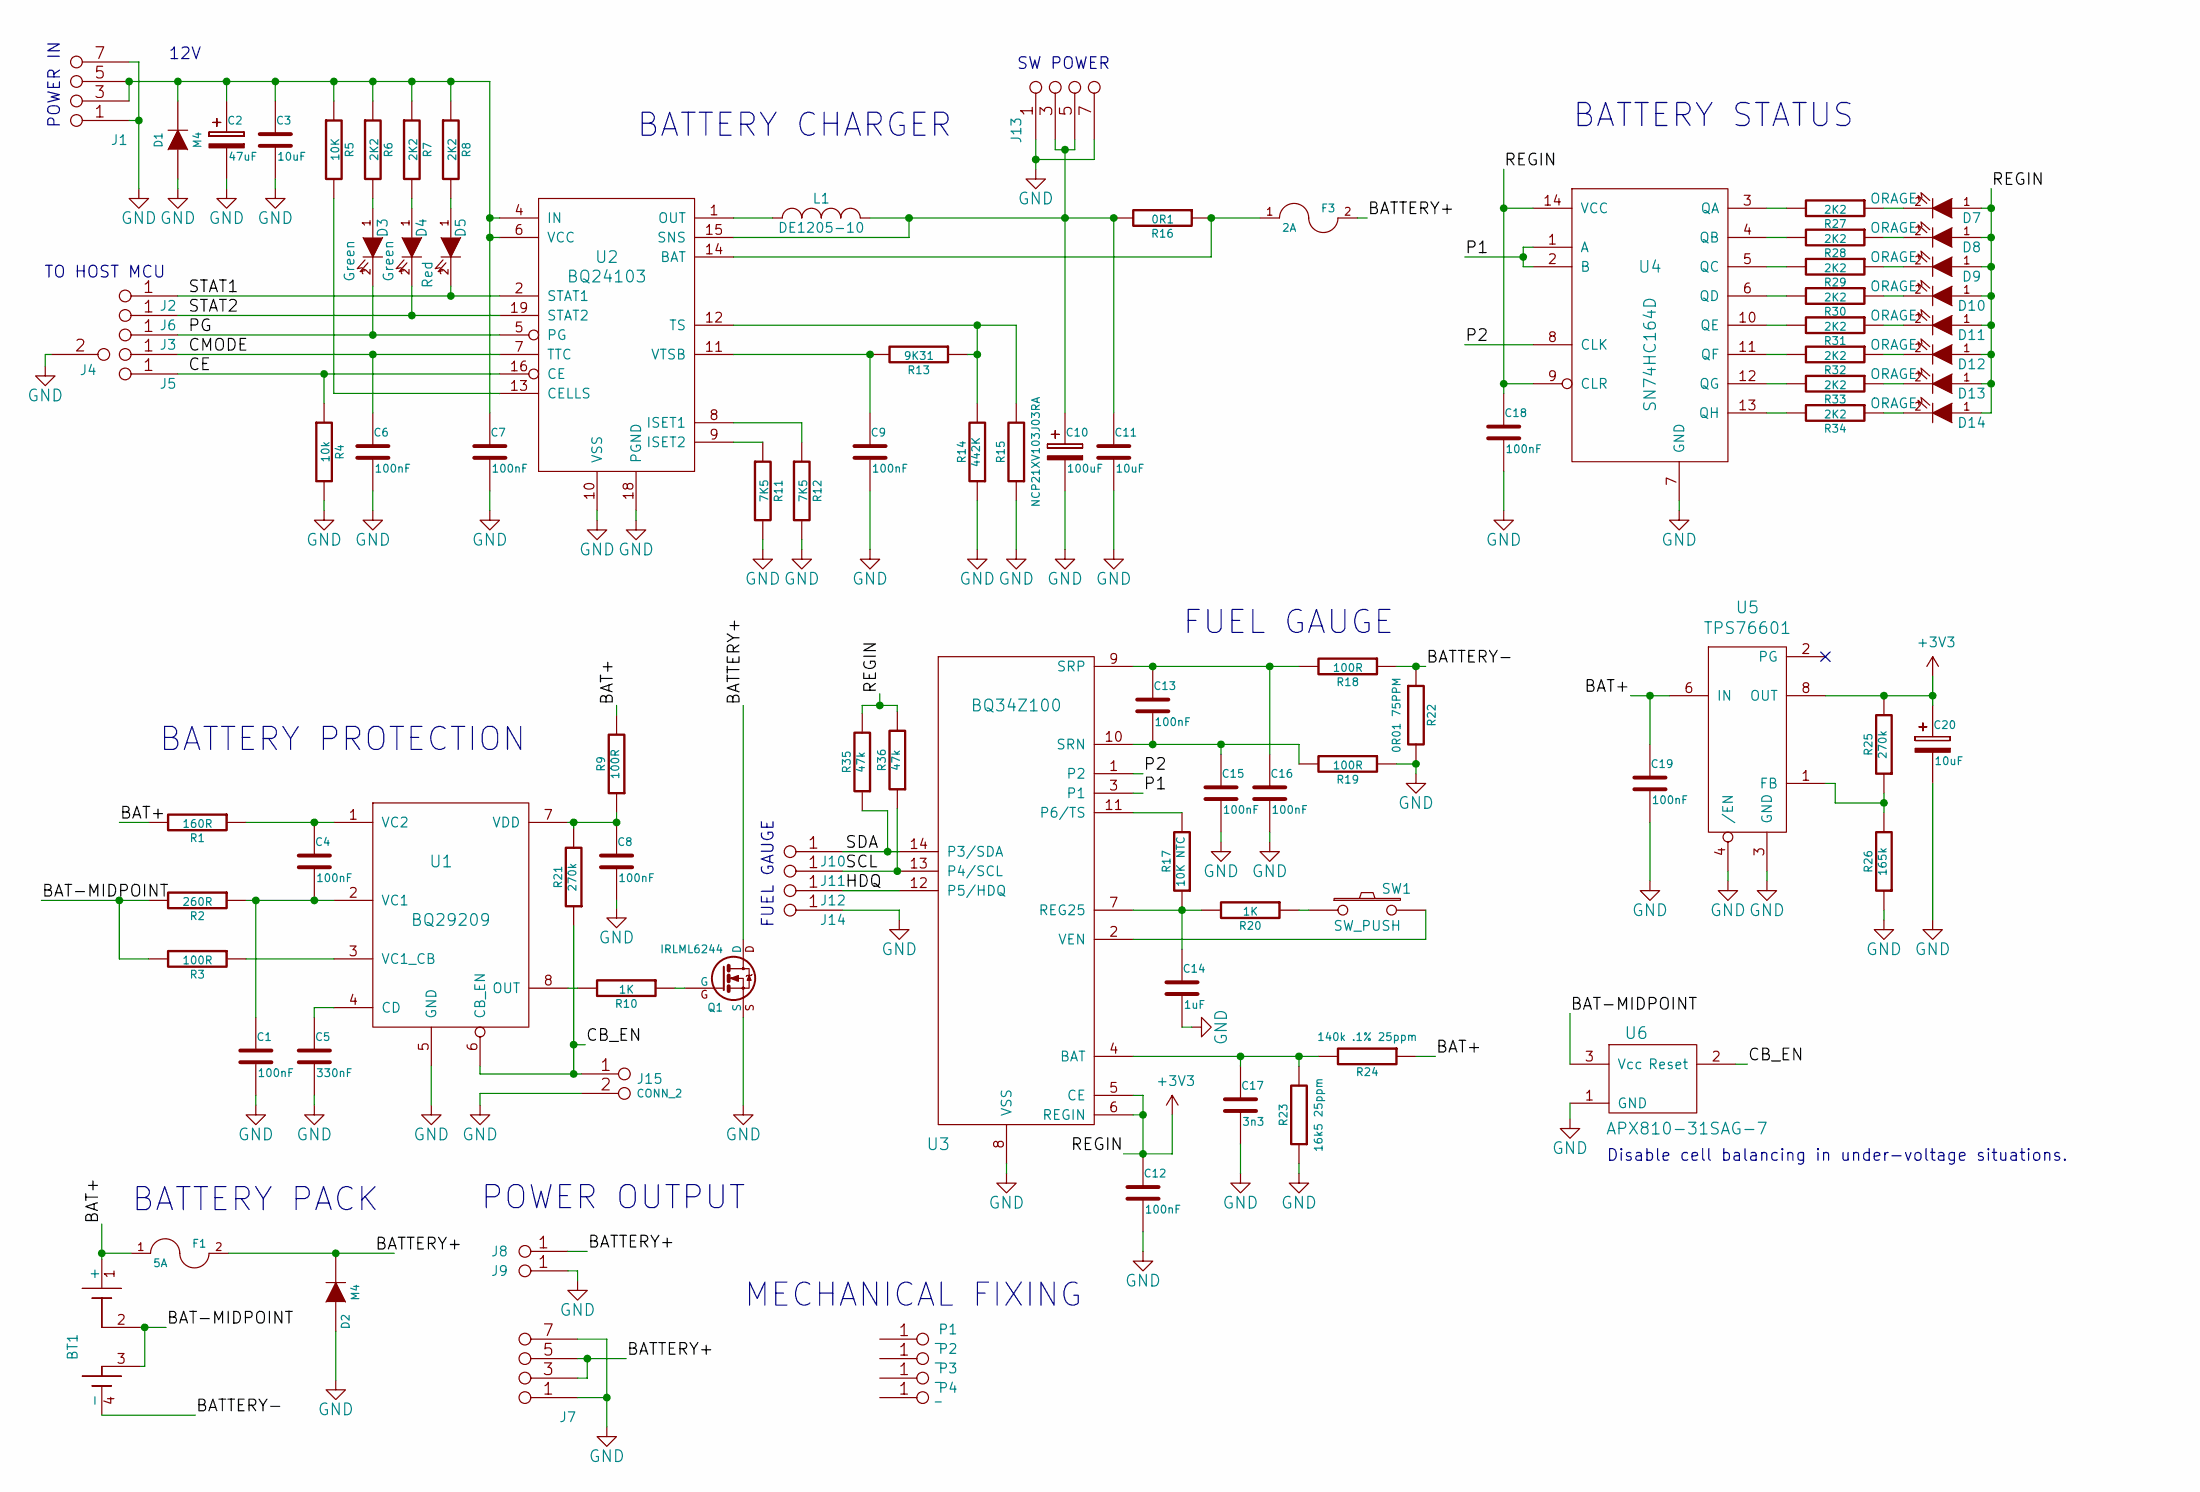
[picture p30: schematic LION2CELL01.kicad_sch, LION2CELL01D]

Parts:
BT1: 2x18650_LION-RESCUE-LION2CELL01C; 2LION
C1, C4, C6, C7, C8, C9, C12, C13, C15, C16, C18, C19: 100nF; SMD-0805
C2: 47uF; TantalC_SizeC_Reflow
C3, C11: 10uF; SMD-0805
C5: 330nF; SMD-0805
C10: 100uF; TantalC_SizeD_Reflow
C14: 1uF; SMD-0805
C17: 3n3; SMD-0805
C20: 10uF; TantalC_SizeB_Reflow
D1, D2: M4; SMA_Standard
D3, D4: Green; LED_1206
D5: Red; LED_1206
D7, D8, D9, D10, D11, D12, D13, D14: ORAGE; LED_1206
F1: 5A; Drzak_2410
F3: 2A; Drzak_2410
J1, J7, J13: JUMP_4X2; Straight_2x04
J2, J3, J5, J6, J10, J11, J12, J14: JUMP_2x1; Straight_1x02
J4: JUMP2_2x1
J8, J9: CONN1_1; WAGO256
J15: CONN_2; SMD_1_2x2
L1: DE1205-10
P1, P2, P3, P4: _; MountingHole_3mm
Q1: IRLML6244; SOT-23
R1: 160R; SMD-0805
R2: 260R; SMD-0805
R3, R9, R18, R19: 100R; SMD-0805
R4: 10k; SMD-0805
R5: 10K; SMD-0805
R6, R7, R8, R27, R28, R29, R30, R31, R32, R33, R34: 2K2; SMD-0805
R10, R20: 1K; SMD-0805
R11, R12: 7K5; SMD-0805
R13: 9K31; SMD-0805
R14: 442K; SMD-0805
R15: NCP21XV103J03RA; SMD-0805
R16: 0R1; R_2512
R17: 10K NTC; SMD-0805
R21, R25: 270k; SMD-0805
R22: 0R01 75PPM; SMD-2512
R23: 16k5 25ppm; SMD-0805
R24: 140k .1% 25ppm; SMD-0805
R26: 165k; SMD-0805
R35, R36: 47k; SMD-0805
SW1: SW_PUSH; SW_PUSH_SMALL
U1: BQ29209; VSON-8
U2: BQ24103; VQFN-20
U3: BQ34Z100; TSSOP-14_4.4x5mm_Pitch0.65mm
U4: SN74HC164D; SO-14
U5: TPS76601; SO-8
U6: APX810-31SAG-7; SOT-23

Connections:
+3V3: C12.1, C18.1, C20.1, D7.1 (A), D8.1 (A), D9.1 (A), D10.1 (A), D11.1 (A), D12.1 (A), D13.1 (A), D14.1 (A), R25.2, R35.2, R36.2, U3.5 (CE), U3.6 (REGIN), U4.9 (CLR), U4.14 (VCC), U5.7 (OUT), U5.8 (OUT)
/BAT+: BT1.1 (+), C19.1, F1.1, R1.2, R9.2, R24.1, U5.5 (IN), U5.6 (IN)
/BAT-MIDPOINT: BT1.2, BT1.3, R2.2, R3.2, U6.3 (Vcc)
/BATTERY+: D2.2 (K), F1.2, F3.2, J7.3 (4), J7.4, J7.5, J7.6 (5), J8.1, Q1.D
/BATTERY-: BT1.4 (-), R18.1, R22.1
/CB_EN: J15.1, R21.1, U1.6 (CB_EN), U6.2 (Reset)
/CE: J5.1, J5.2, R4.1, U2.16 (CE)
/CMODE: C6.1, J4.1, U2.7 (TTC)
/HDQ: J12.1, J12.2, U3.12 (P5/HDQ)
/P1: U3.3 (P1), U4.1 (A), U4.2 (B)
/P2: U3.1 (P2), U4.8 (CLK)
/PG: D3.2 (K), J3.1, J3.2, U2.5 (PG)
/SCL: J11.1, J11.2, R36.1, U3.13 (P4/SCL)
/SDA: J10.1, J10.2, R35.1, U3.14 (P3/SDA)
/STAT1: D5.2 (K), J2.1, J2.2, U2.2 (STAT1)
/STAT2: D4.2 (K), J6.1, J6.2, U2.19 (STAT2)
GND: C1.2, C2.2, C3.2, C5.2, C6.2, C7.2, C8.2, C9.2, C10.2, C11.2, C12.2, C14.2, C15.2, C16.2, C17.2, C18.2, C19.2, C20.2, D1.1 (A), D2.1 (A), J1.1 (2), J1.2, J1.7 (8), J1.8, J4.2, J7.1 (2), J7.2, J7.7 (8), J7.8, J9.1, J13.1 (2), J13.2, J13.7 (8), J13.8, J14.1, J14.2, J15.2 (PM), Q1.S, R4.2, R11.2, R12.2, R14.1, R15.1, R19.1, R22.2, R23.1, R26.1, U1.5 (GND), U1.9 (GND), U2.10 (VSS), U2.17 (PGND), U2.18 (PGND), U2.21 (pgnd), U3.8 (VSS), U4.7 (GND), U5.3 (GND), U5.4 (/EN), U6.1 (GND)
unnamed: C1.1, C4.2, R2.1, U1.2 (VC1)
unnamed: C2.1, C3.1, C7.1, D1.2 (K), J1.3 (4), J1.4, J1.5, J1.6 (5), R5.1, R6.1, R7.1, R8.1, U2.3 (IN), U2.4 (IN), U2.6 (VCC)
unnamed: C4.1, R1.1, U1.1 (VC2)
unnamed: C5.1, U1.4 (CD)
unnamed: C8.1, R9.1, R21.2, U1.7 (VDD)
unnamed: C9.1, R13.2, U2.11 (VTSB)
unnamed: C10.1, C11.1, J13.3 (4), J13.4, J13.5, J13.6 (5), L1.2, R16.2, U2.15 (SNS)
unnamed: C13.1, C16.1, R18.2, U3.9 (SRP)
unnamed: C13.2, C15.1, R19.2, U3.10 (SRN)
unnamed: C14.1, R17.1, R20.2, U3.7 (REG25)
unnamed: C17.1, R23.2, R24.2, U3.4 (BAT)
unnamed: D3.1 (A), R6.2
unnamed: D4.1 (A), R7.2
unnamed: D5.1 (A), R8.2
unnamed: D7.2 (K), R27.1
unnamed: D8.2 (K), R28.1
unnamed: D9.2 (K), R29.1
unnamed: D10.2 (K), R30.1
unnamed: D11.2 (K), R31.1
unnamed: D12.2 (K), R32.1
unnamed: D13.2 (K), R33.1
unnamed: D14.2 (K), R34.1
unnamed: F3.1, R16.1, U2.14 (BAT)
unnamed: L1.1, U2.1 (OUT), U2.20 (OUT)
unnamed: Q1.G, R10.1
unnamed: R3.1, U1.3 (VC1_CB)
unnamed: R5.2, U2.13 (CELLS)
unnamed: R10.2, U1.8 (OUT)
unnamed: R11.1, U2.9 (ISET2)
unnamed: R12.1, U2.8 (ISET1)
unnamed: R13.1, R14.2, R15.2, U2.12 (TS)
unnamed: R17.2, U3.11 (P6/TS)
unnamed: R20.1, SW1.1
unnamed: R25.1, R26.2, U5.1 (FB)
unnamed: R27.2, U4.3 (QA)
unnamed: R28.2, U4.4 (QB)
unnamed: R29.2, U4.5 (QC)
unnamed: R30.2, U4.6 (QD)
unnamed: R31.2, U4.10 (QE)
unnamed: R32.2, U4.11 (QF)
unnamed: R33.2, U4.12 (QG)
unnamed: R34.2, U4.13 (QH)
unnamed: SW1.2, U3.2 (VEN)

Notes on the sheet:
BATTERY CHARGER
BATTERY STATUS
BATTERY PACK
POWER OUTPUT
Disable cell balancing in under-voltage situations.
MECHANICAL FIXING
TO HOST MCU
BATTERY PROTECTION
SW POWER
FUEL GAUGE
12V
POWER IN

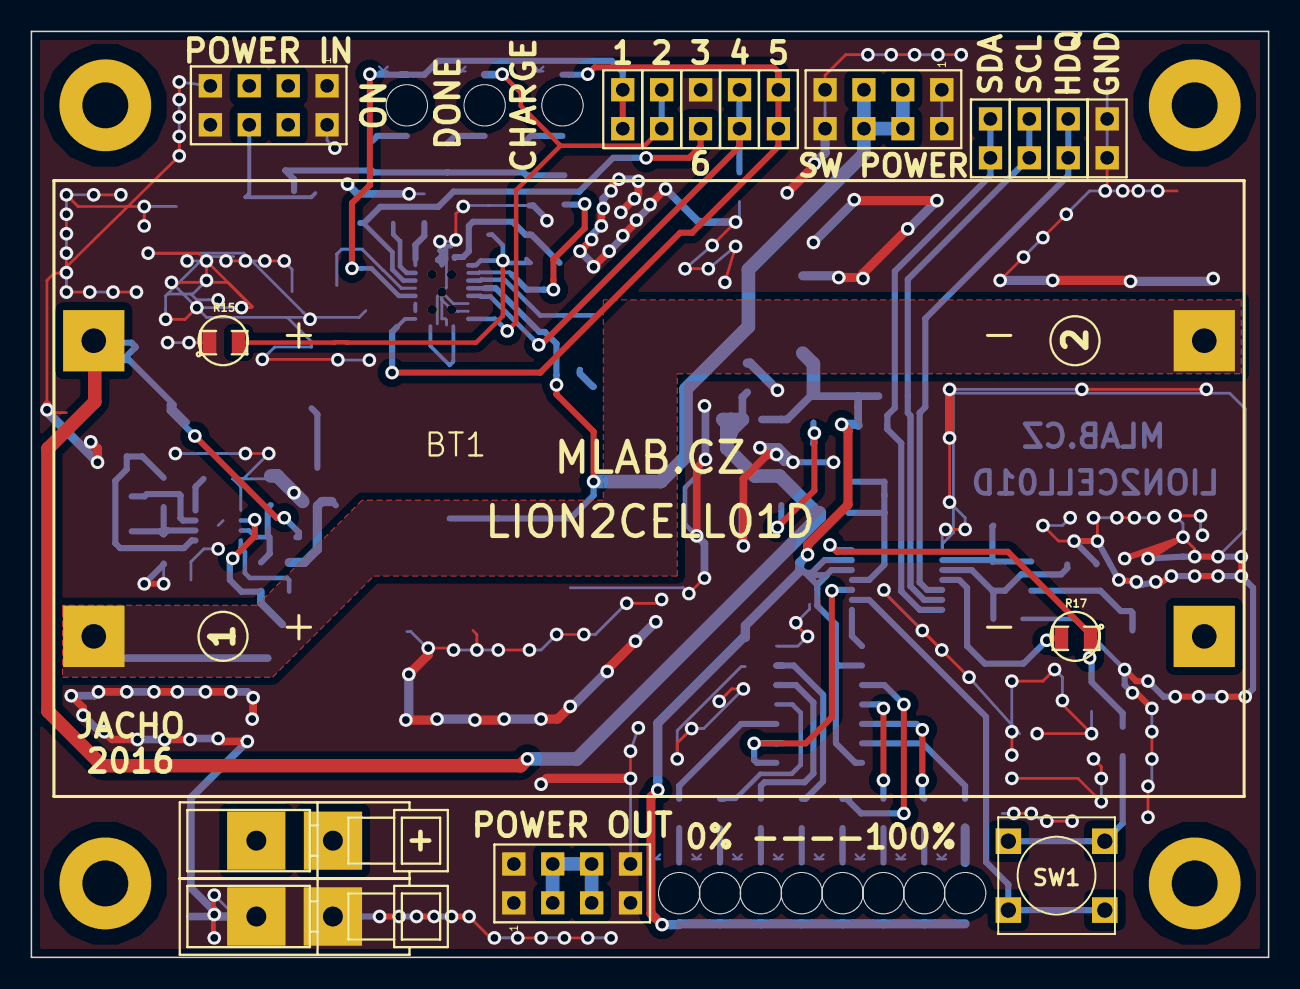
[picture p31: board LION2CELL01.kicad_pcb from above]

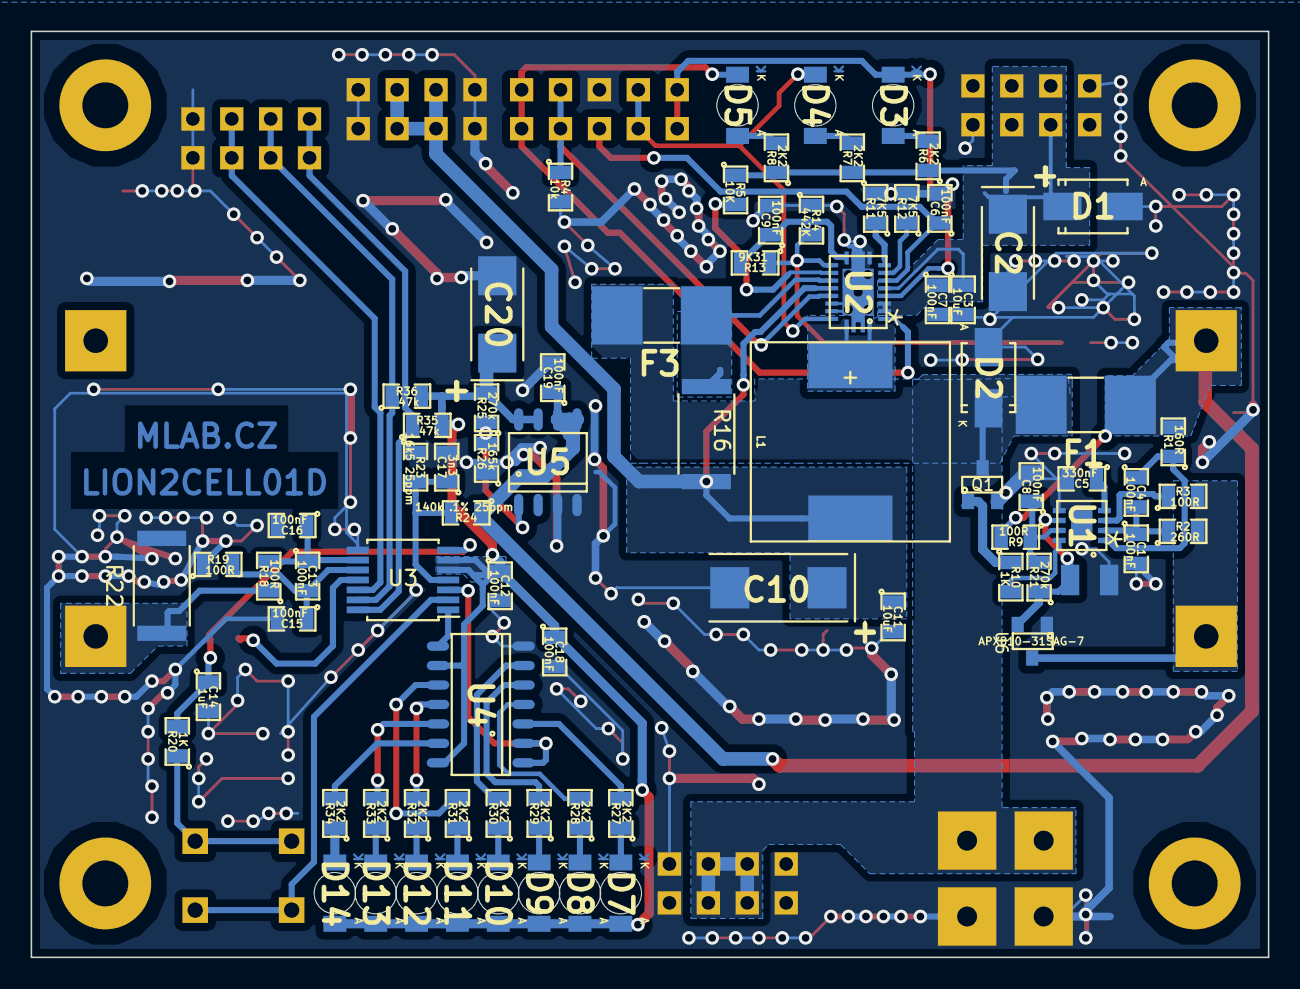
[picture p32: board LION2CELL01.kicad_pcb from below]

Board: 2 copper layers, 80.8 x 60.5 mm, 100 parts (78 on the bottom side), 60 nets.

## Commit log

2017-08-22 rename category folders
    [6x8MLAB_frame.scad, 6x8MLAB_frame.stl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]
2017-08-22 rename files and module folders
    [6x8MLAB_frame.scad, 6x8MLAB_frame.stl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]
2017-08-22 create hw folder
    [LION2CELL01D-B.Cu.gbr, LION2CELL01D-B.Mask.gbr, LION2CELL01D-Edge.Cuts.gbr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]
2017-12-28 Code style cleanup.
    [6x8MLAB_frame.scad]
2020-10-30 Documentation update.
    [LION2CELL01D.kicad_pcb, LION2CELL01D.kicad_sch]
2021-05-31 Switch driver selection to hid.
2021-05-31 Add gcode for Be3D edee printer.
2021-06-02 Update documentation. Improve schematic (title block, texts) Regenerate PDF export.
    [LION2CELL01D.kicad_pcb, LION2CELL01D.kicad_sch, LION2CELL01D.sch]
2021-06-12 Add information about charging current.
2022-04-06 Update actions products
    [LION2CELL01D-B.Cu.gbr, LION2CELL01D-B.Mask.gbr, LION2CELL01D-Edge.Cuts.gbr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]
2022-07-20 Update title block and assets submodule.
    [LION2CELL01D.kicad_sch]
2024-07-17 Update to KiCADv8 project.
    [LION2CELL01.kicad_pcb, LION2CELL01.kicad_sch, LION2CELL01D.kicad_pcb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]
